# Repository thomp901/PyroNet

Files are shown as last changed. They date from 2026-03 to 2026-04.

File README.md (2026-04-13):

# PyroNet
Early Fire Detection: Purdue Senior Design Project

Team Members:
Sebastian Carrizosa
Kameron Jackson
Diego Ramirez
Garrison Thompson

## Download Specific Folders

To download **only** the a specific folder (e.g. hardware/, csp/) that contains the relevant files, run the following commands:

```bash
git clone --filter=blob:none --no-checkout https://github.com/thomp901/PyroNet.git
cd PyroNet
git sparse-checkout init --cone
git sparse-checkout set FOLDER/
git checkout main
```

Replace `FOLDER` with the specfic folder.

Then, you can `pull`, `add`, `commit`, and `push` like normal.

## Pushing

To push, go to the project directory in your terminal and enter the following commands:

```bash
git add .
git commit -m 'YOUR MESSAGE'
git push
```

Replace `YOUR MESSAGE` with a brief description of your changes.

## Discarding your changes

To **discard your changes** and pull the latest version, enter: 

```bash
git fetch --all
git reset --hard origin/main
```

> [!WARNING]
> Warning: This will permanently delete any local work.

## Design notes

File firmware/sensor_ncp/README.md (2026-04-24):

## sensor_ncp

This project builds the `sensor_ncp` firmware for the custom `BDE-MB1352P71` carrier-board target in this repository. It is not a LaunchPad project, even though SysConfig still uses `LP_CC1352P7_1` as the generic device context.

The current host boundary is a phase-1 binary UART protocol on `UART0`:

- UART pins: TX=`DIO_28`, RX=`DIO_27`
- UART settings: `115200 8N1`, no flow control
- Framing: `0xA5 0x5A`, version `0x01`, CRC-16/CCITT-FALSE
- Implemented message types: `HELLO`, `HELLO_ACK`, `PING`, `PONG`, `GET_STATUS`, `STATUS`, `ERROR`

The NCP owns only the link skeleton in this phase:

- waits for `HELLO`
- replies with `HELLO_ACK`
- enters `LINK_READY`
- responds to `PING` with `PONG`
- responds to `GET_STATUS` with placeholder `STATUS`

The production UART boundary is binary only. The earlier ASCII command bootstrap path is no longer the active transport.

## Hardware Notes

- Target module: `BDE-MB1352P71`
- Verified SWO / ITM trace pin: `DIO_16`
- Reserved BDE module pins must remain untouched:
  - `DIO_8`, `DIO_9`, `DIO_10`, `DIO_20` are used by on-module SPI flash
  - `DIO_29`, `DIO_30` are used by the RF switch
- XOSC cap settings for this module must remain:
  - `CCFG.xoscCapArray = true`
  - `CCFG.xoscCapArrayDelta = 0x00`

## Verified Build

```sh
cd /Users/diegosmacbook/Documents/PyroNet/firmware/sensor_ncp
make -C freertos/ticlang \
  SIMPLELINK_CC13XX_CC26XX_SDK_INSTALL_DIR=/Users/diegosmacbook/ti/simplelink_cc13xx_cc26xx_sdk_8_32_00_07 \
  SYSCONFIG_TOOL=/Applications/ti/ccs2050/ccs/utils/sysconfig_1.27.0/sysconfig_cli.sh \
  TICLANG_ARMCOMPILER=/Applications/ti/ti-cgt-armllvm_5.1.0.LTS \
  clean all
```

Build output:

- `freertos/ticlang/sensor_ncp.out`

## Verified Flash

```sh
cd /Users/diegosmacbook/Documents/PyroNet/firmware/sensor_ncp
/Applications/ti/uniflash_9.5.0/dslite.sh \
  --config=tools/cc1352p7_2pin_cJTAG_XDS110.ccxml \
  -e \
  freertos/ticlang/sensor_ncp.out
```

## Wi-SUN Profile

The current image is configured for the running PyroNet border router:

- FAN: `1.1`
- Device role: `FFN`
- Network name: `PyroNet`
- Regulatory domain: `NA`
- Channel plan ID: `1`
- PHY mode ID: `0x02`
- Security: certificate-based

Repo-local credentials are expected at:

- `certs/ca_cert.pem`
- `certs/node_cert.pem`
- `certs/node_key.pem`

These are compiled through `application/wisun_certificates.h`.

## Verified Runtime Status

The current image has been verified to:

- boot on the custom board
- emit SWO / ITM trace on `DIO_16`
- start the TI Wi-SUN stack
- reach `CON_STATUS_CONNECTING` in local trace output
- join the running `PyroNet` border router

Join success was confirmed from the border-router side by observing:

- advertisement and configuration exchange
- DHCPv6 reply
- ARO registration for `fd12:3456::212:4b00:28ed:d802`
- RPL DAO and DAO-ACK

## SWO / ITM Capture

Verified helper:

```sh
cd /Users/diegosmacbook/Documents/PyroNet/firmware/sensor_ncp
python3 tools/capture_itm_text.py /dev/cu.usbmodemLS41069U4 3000000 --seconds 15
```

Repo-root shortcuts:

```sh
make build
make flash
make run
make watch
make bootlog
```

Persistent logging:

```sh
cd /Users/diegosmacbook/Documents/PyroNet/firmware/sensor_ncp
python3 tools/swo_log_daemon.py
```

This writes timestamped daily files under `logs/swo/` and will reconnect if the XDS110 aux port disappears and reappears.

Persistent terminal trace:

```sh
cd /Users/diegosmacbook/Documents/PyroNet/firmware/sensor_ncp
make watch
```

This starts the TI DSS probe hold-open session and streams decoded SWO text directly in the terminal while also writing `logs/swo/swo_YYYY-MM-DD.log`. On Apple Silicon, the wrapper will automatically use TI's bundled x86_64 Java runtime when available.

To install it as a macOS user `launchd` agent:

```sh
cd /Users/diegosmacbook/Documents/PyroNet/firmware/sensor_ncp
python3 tools/install_swo_logger_launchd.py install
```

Notes:

- the exact `/dev/cu.usbmodem...` node may vary
- `make watch` auto-detects the XDS110 aux port by default; set `SWO_PORT=/dev/cu.usbmodem...` to pin it
- this hardware uses the XDS110 aux COM path mapped to target `TDO` on `DIO_16`
- `tools/capture_itm_text.py` includes a fallback decoder for this image's raw SWO byte pattern
- the simplest reliable one-shot capture is `make bootlog`, which starts capture first and then reflashes to force a fresh boot

## Reference Trees

These are reference-only and must not be edited in place:

- `../wisun_soc_cli`
- `../wisun_rcp`
- TI SDK example content under `/Users/diegosmacbook/ti/simplelink_cc13xx_cc26xx_sdk_8_32_00_07`

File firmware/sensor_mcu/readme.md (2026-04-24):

# sensor_mcu

This firmware exposes a dedicated SWO debug path through [debug_console.c](./debug_console.c)
and [debug_console.h](./debug_console.h). The implementation uses:

- ITM stimulus port `0` for application log output
- PA03 as the SWO pin
- NRZ SWO at a target bitrate of `875000`
- a stable boot-ready marker of `SWO_BOOT_READY`

The firmware emits two boot lines during `app_init()`:

- `SWO_BOOT backend=SWO port=0 speed=<actual>`
- `SWO_BOOT_READY`

The current sensor bring-up path also probes and initializes the shared I2C bus
during `app_init()`:

- SPS30 at address `0x69`
- BME68x at address `0x76`

Probe output is emitted over the same log path from [sensor_bus.c](./sensor_bus.c):

- `SENSOR_FOUND name=SPS30 addr=0x69` when the SPS30 ACKs
- `SENSOR_PROBE name=SPS30 addr=0x69 status=<status>` when the SPS30 does not ACK cleanly
- `BSEC_READY addr=0x76` when the BME688/BSEC stack is initialized
- `SPS30_READY addr=0x69 fw=<major>.<minor>` when the SPS30 stack is initialized
- `SENSORS_READY bme68x=<0|1> sps30=<0|1>` after bring-up completes, reflecting
  initialized sensor services rather than probe-only presence

Once boot is complete, the firmware runs the non-stretch sensing path:

- BME688/BSEC air-quality acquisition with one immediate bootstrap reading on
  the first successful BME688 measurement, then a fixed 10-second app cadence
- PM2.5 acquisition through the SPS30 on the same fixed 10-second app cadence
- `SENSOR_READING ...`, `GAS_DIAGNOSTIC ...`, and `RISK_LEVEL ...` SWO lines
  when live sensor readings are forwarded into the risk service

Use the repo `Makefile` for the normal host workflow:

```sh
make verify-swo
```

That will build, flash, and read SWO until `SWO_BOOT_READY` is observed.

To read SWO directly through the SI-DBG1015A in SWD mode, run:

```sh
"$HOME/.silabs/slt/installs/archive/Commander.app/Contents/MacOS/commander" \
  swo read \
  --device EFR32FG28A122F1024GM48 \
  --serialno 440365444 \
  --tif SWD \
  --swospeed 875000 \
  --timeout 5 \
  --endmarker "SWO_BOOT_READY"
```

Use `--noreset` if the target is already running and you only want to attach to
an existing session, or run:

```sh
make swo-attach TIMEOUT=5
```

If you add temporary SWO diagnostics while debugging, keep them short and
remove or reduce them once verification is complete.

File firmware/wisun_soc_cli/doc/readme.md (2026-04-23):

# Wi-SUN - SoC CLI

The Wi-SUN CLI (Command-Line Interface) sample application allows developers to easily evaluate the Wi-SUN stack APIs. The Wi-SUN command-line interface provides a serial interface to a number of the Wi-SUN stack functions. For example, it can be used to connect the Wi-SUN device to a Wi-SUN border router and exchange IP packets or perform RF tests.

## Getting Started

To get started with Wi-SUN and Simplicity Studio, see [QSG181: Wi-SUN SDK Quick Start Guide](https://www.silabs.com/documents/public/quick-start-guides/qsg181-wi-sun-sdk-quick-start-guide.pdf).

> NB: The Wi-SUN CLI application, as opposed to most other Wi-SUN sample applications, is not in 'auto-connect' mode by default. This means that the user has to set the network parameters and trigger the connection manually following a reset. This is visible when calling `wisun get wisun.join_state` in the console (the result will be `wisun.join_state = Disconnected (0)`). To change this behavior, use `wisun set app.autoconnect 1` followed by `wisun save` (when 'auto-connect' is active, a `Connecting...` message will be visible following a reset, with `Join_state: Select PAN...`).

This example exposes a command-line interface to interact with the Wi-SUN stack. To get started with the example, follow the steps below:

* Flash the "Wi-SUN Border Router" demonstration to a device and start the Border Router.
* Create and build the Wi-SUN CLI project.
* Flash the Wi-SUN CLI project to a second device.
* Using Simplicity Studio, open a console on the device running the Wi-SUN CLI project.

See the associated sections in [QSG181: Wi-SUN SDK Quick Start Guide](https://www.silabs.com/documents/public/quick-start-guides/qsg181-wi-sun-sdk-quick-start-guide.pdf) for step-by-step guidelines for each operation. To fully evaluate the Wi-SUN CLI features, another device running the Wi-SUN CLI application might be required. The Wi-SUN CLI application can also interact with the other Wi-SUN examples (Wi-SUN Ping, Wi-SUN TCP/UDP Server/Client...).

> The Wi-SUN CLI example can be used to evaluate and test the Wi-SUN stack but should not be used to create production applications (due to its large footprint related to all PHYs being allowed). Developers should implement their own C application running in the EFR32 and using the Wi-SUN stack API, starting from simpler example applications.

## Wi-SUN CLI Commands

To see the available commands, enter the following command in the console.

    wisun help

The list of available commands is output on the console with the associated help. Following is an extended description and examples of how to use each command.

| Command | Description | Example |
|---|---|---|
| wisun get \<section>.[setting] | Get a setting variable. Specifying only the section retrieves all settings of the section. | > wisun get wisun.ip_addresses<br>> wisun get wisun <br>>  wisun get wisun.join_state <br>> wisun get statistics <br>> wisun get app |
| wisun set \<section>.[setting] \<value> | Set a setting variable | > wisun set wisun.network_size test |
| wisun join_fan10 | Connect to the selected Wi-SUN FAN1.0 network | > wisun join_fan10 |
| wisun join_fan11 | Connect to the selected Wi-SUN FAN1.1 network | > wisun join_fan11 |
| wisun join_explicit | Connect to a Wi-SUN (FSK only) network using explicit channel settings| > wisun join_explicit |
| wisun join_ids | Connect to a Wi-SUN network using radio conf ids| > wisun join_ids |
| wisun join_custom_fsk | Connect to a Wi-SUN network using custom FSK PHY settings | > wisun join_custom_fsk |
| wisun join_custom_ofdm | Connect to a Wi-SUN network using custom OFDM PHY settings | > wisun join_custom_ofdm |
| wisun join_custom_oqpsk | Connect to a Wi-SUN network using custom OQPSK PHY settings | > wisun join_custom_oqpsk |
| wisun disconnect | Disconnect from the Wi-SUN network | > wisun disconnect |
| wisun mac_allow \<mac address> | Add an allowed MAC address to the access list<br>broadcast address: allow all MAC addresses<br>unique address: allow the given MAC address | > wisun mac_allow ff:ff:ff:ff:ff:ff:ff:ff<br>> wisun mac_allow ffffffffffffffff |
| wisun mac_deny \<mac address>  | Add a denied MAC address to the access list<br>broadcast address: deny all MAC addresses<br>unique address: deny the given MAC address | > wisun mac_deny 00:01:02:03:04:05:06:07<br>> wisun mac_deny 0001020304050607 |
| wisun ping \<remote address> | Ping a remote host | > wisun ping fd00:7283:7e00:0:fd6f:d00:a8c0:20fe |
| wisun reset | Reset variables to default values | > wisun reset |
| wisun save | Save variables to NVM | > wisun save |
| wisun socket_close \<socket> | Close an open socket | > wisun socket_close 3 |
| wisun socket_list | List open sockets | > wisun socket_list |
| wisun socket_read \<socket> \<amount of bytes> | Read buffered data from a socket | > wisun socket_read 3 14 |
| wisun socket_set_option \<socket> \<option> \<option data> | Configure a socket | > wisun socket_set_option 3 event_mode indication |
| wisun socket_write \<socket> \<string> | Write a string to a socket | > wisun socket_write 3 "hello world" |
| wisun socket_writeto \<socket> \<remote address> \<remote port> \<string\> | Write a string to an unconnected socket, i.e. UDP server socket | > wisun socket_writeto 3 fc00::1 5001 "hello world" |
| wisun tcp_client \<remote address> \<remote port> | Open a TCP connection to a remote host | > wisun tcp_client fd24:120b:802c:0001:705d:9179:8607:fd21 5001 |
| wisun tcp_server \<local port> | Open a TCP server port | > wisun tcp_server 5001 |
| wisun udp_client \<remote address> \<remote port> | Open a UDP connection to a remote host | > wisun udp_client fd00:6172:6d00:0:3038:5115:26:27 7 |
| wisun udp_server \<local port> | Open a UDP server port | > wisun udp_server 5001 |
| wisun socket_get_option \<socket> \<option> | Get a socket option | > wisun socket_get_option |
| wisun clear_credential_cache | Clear the wisun credential cache | > wisun clear_credential_cache |
| wisun reset_statistics | Reset the statistics | > wisun reset_statistics |
| wisun set_trace_level \<string> | Set [trace level](https://docs.silabs.com/wisun/latest/wisun-stack-api/sl-wisun-types#sl-wisun-trace-level-t) for a [trace group](https://docs.silabs.com/wisun/latest/wisun-stack-api/sl-wisun-types#sl-wisun-trace-group-t) | > wisun set_trace_level all,debug<br>[Set 64 trace groups]<br>> wisun set_trace_level 1,none;4,info<br>[Set 2 trace groups]|
| wisun set_lfn_support \<lfn_limit> | configure LFN support: <br> - [uint8] lfn_limit: Number of LFN children | > wisun set_lfn_support 3 |
| wisun mode_switch \<mode> \<phy_mode_id> \<neighbor_mac_address> |  configure mode switch: <br> - [uint8] mode: 0=disabled, 1=enabled, 2=default <br> - [uint8] PhyModeID <br> - [string] neighbor MAC address (optional) | > wisun mode_switch 1 84 <br> > wisun mode_switch 1 84 01:02:03:04:05:06:07:08 |
| wisun trigger \<frame type> | Trigger a transmission of a periodic frame <br> - [string] pas: PAN Advertisement Solicit, pa: PAN Advertisement, pcs: PAN Configuration Solicit, pc: PAN Configuration, dis: DODAG Information Solicitation, dio: DODAG Information Object | > wisun trigger pas |
| wisun getsockname \<socket> | Get local IP address of the socket | > wisun getsockname 3 |
| wisun getpeername \<socket> | Get peer IP address of the socket | > wisun getpeername 3 |
| wisun set_leaf \<is_leaf> | Set Leaf behavior <br> - [uint8] state: 0=disabled, 1=enabled <br> | > wisun set_leaf 1 |
| wisun set_phy_sens \<phy_mode_id> \<sensitivy> | Set the sensitivity for the given PhyModeID <br> - [uint8] PhyModeID <br> - [int16] sensitivy in dBm | > wisun set_phy_sens 1 -70 |
| wisun set_direct_connect_state \<state> | Set Direct Connect state <br> - [uint8] state: 0=disabled, 1=enabled <br> | wisun set_direct_connect_state 1 |
| wisun accept_direct_connect_link \<remote address> | Accept a Direct Connect link request | wisun accept_direct_connect_link fe80::b6e3:f9ff:fec5:83df |
| wisun concurrent_detection \<state> | Configure concurrent detection <br> - [uint8] state: 0=disabled, 1=enabled <br> | > wisun concurrent_detection 1 |
| wisun reset_duty_cycle | Reset the duty cycle counters | > wisun reset_duty_cycle |

## Wi-SUN Settings

The command-line interface maintains a number of settings. The Wi-SUN settings are distributed in three sections: *wisun*, *statistics*, and *app*. They can be listed by entering:

    wisun get <section name>

The Wi-SUN stack settings are listed with their current state/value. Some of them can be modified by using the following command prototype:

    wisun set <section name>.<settings name> <value>

To modify the network name the Wi-SUN device should connect to, enter:

    wisun set wisun.network_name "My Network"

Next time you issue the `wisun join_xxxxx` command, the device starts a connection process with the Wi-SUN network named "My Network".

### Matching a `wsbrd` Border Router

For a border router configured with:

    network_name = Wi-SUN\x20Network
    domain = NA
    chan_plan_id = 1
    phy_mode_id = 0x02

the default client settings in this project already match those values through `config/wisun/wisun_settings.wisunconf`.

The equivalent runtime CLI commands are:

    wisun set wisun.network_name "Wi-SUN Network"
    wisun set wisun.regulatory_domain NA
    wisun set wisun.chan_plan_id 1
    wisun set wisun.phy_mode_id 2
    wisun save

This project also stores the client credential material in `config/wisun/wisun_settings.wisunconf`:

- `devicePrivateKey`: node private key
- `deviceCertificate`: node certificate
- `caCertificate`: trusted CA certificate

These must match the border router CA, while the node certificate and key must remain distinct from the border router certificate and key.

### *wisun* Section Settings

- The settings in the *wisun* section are directly related to the Wi-SUN stack behavior. A detailed settings list can be found below.
- Writable settings are valid for all PHYs unless it is specified otherwise in the last column .

| Variable | R/W | Type | Values | Description | Applies to |
|---|-----|---|---|---|---|
| wisun.network_name | R/W | string | up to 31 ASCII characters. Use double quotes (") to include spaces | Name of the Wi-SUN network |  |
| wisun.phy_config_type | R | string | - FAN1.0 (0) <br> - FAN1.1 (1) <br> - explicit (2) <br> - IDs (3) | Wi-SUN PHY configuration type (depends on the `wisun join_xxxx` used) |  |
| wisun.regulatory_domain | R/W | integer | - WW (0): Worldwide<br> - NA (1): North America<br> - JP (2): Japan<br> - EU (3): Europe<br> - CN (4): China<br> - IN (5): India<br> - MX (6): Mexico<br> - BZ (7): Brazil<br> - AZ (8): Australia/New Zealand<br> - KR (9): South Korea<br> - PH (10): Philippines<br> - MY (11): Malaysia<br> - HK (12): Hong Kong<br> - SG (13): Singapore<br> - TH (14): Thailand<br> - VN (15): Vietnam | Regulatory domain of the Wi-SUN network | - FAN1.0 <br> - FAN1.1 |
| wisun.operating_class | R/W | integer | 1 to 4 | Wi-SUN FAN1.0 operating class | FAN1.0 |
| wisun.operating_mode | R/W | integer | - 0x1a (1a) <br> - 0x1b (1b) <br> - 0x2a (2a) <br> - 0x2b (2b) <br> - 0x3 (3) <br> - 0x4a (4a) <br> - 0x4b (4b) <br> - 0x5 (5) | Wi-SUN FAN1.0 operating mode | FAN1.0 |
| wisun.network_size | R/W | integer | - automatic (0) <br> - small (default): less than 100 nodes (1) <br> - medium: 100 to 1000 nodes (2) <br> - large: more than 1000 nodes (3) <br> - test (4) <br> - certification (6) |  Used to optimize network timings considering the number of expected nodes on the network. |  |
| wisun.tx_power | R/W | integer | -45 to 20 | Maximum TX power in dBm |  |
| wisun.tx_power_ddbm | R/W | integer | -450 to 200 | Maximum TX power in deci-dBm |  |
| wisun.unicast_dwell_interval | R/W | integer | 10 to 255 | Unicast dwell interval in milliseconds |  |
| wisun.chan_plan_id | R/W | integer | - Europe: 32-37 <br> - North America: 1-5 <br> - Brazil: 1-5 <br> - Japan: 21-24 | Wi-SUN channel plan ID [uint8] | FAN1.1 |
| wisun.phy_mode_id | R/W | integer | - Europe: <br> FSK without FEC: 1/3/5 <br> FSK FEC: 17/19/21 <br> OFDM: 84-86 <br> - North America: <br> FSK without FEC: 2/3/5/6/8 <br> FSK FEC: 18/19/21/22/24 <br> OFDM: 34-38 / 51-54 / 68-70 / 84-86 <br> - Brazil: <br> FSK without FEC: 2/3/5/6/8 <br> FSK FEC: 18/19/21/22/24 <OFDM> 34-38 / 51-54 / 68-70 / 84-86 <BR> - Japan: <br> FSK without FEC: 2/4/5/7/8 <br> FSK FEC: 18/20/21/23/24 <br> OFDM: 51-54 / 68-70 / 84-86 | Wi-SUN FAN1.1 PHY mode ID | - FAN1.1 <br> - explicit <br> - join by IDs |
| wisun.ch0_frequency | R/W | integer |  | Explicit channel plan: Central frequency of the first channel in kHz | explicit |
| wisun.channel_spacing | R/W | integer | - 100 kHz (0) <br> - 200 kHz (1) <br> - 400 kHz (2) <br> - 600 kHz (3) <br> - 250 KHz (4) <br> - 800kHz (5) <br> - 1200KHz (6) | Explicit channel plan: Channel spacing | explicit |
| wisun.number_of_channels | R/W | integer |  | Explicit channel plan: Number of channels | explicit |
| wisun.protocol_id | R/W | integer |  | Radioconf protocol ID [uint16] | join by IDs |
| wisun.channel_id | R/W | integer |  | Radioconf channel ID [uint16] | join by IDs |
| wisun.ip_addresses | R | list of IPv6 addresses |  | List of all IP addresses assigned to the device |  |
| wisun.border_router | R | list of IPv6 addresses |  | List of known IPv6 addresses of the border router | |
| wisun.parents | R | list of IPv6 addresses |  | List of known IPv6 addresses of the parents |  |
| wisun.neighbors | R | list of IPv6 addresses |  | List of known IPv6 addresses of the RPL neighbors  |  |
| wisun.join_state | R | integer | - Idle (0) <br> - Select PAN (1) <br> - Authenticate (2) <br> - Acquire PAN Config (3) <br> - Configure Routing (4) <br> - Operational (5) | Current join state in the connection process |  |
| wisun.mac_address | R/W | MAC address |  | MAC address to use |  |
| wisun.allowed_channels | R/W | string |  | Allowed channel ranges (e.g. 0-54,57-60,64,67-68) |  |
| wisun.fec | R/W | bool | - disable FEC (0) <br> - enable FEC (1) | Use FEC flag | FAN1.0 |
| wisun.regulation | R/W | string | - None (0) <br> - ARIB (1) | Regional regulation |  |
| wisun.regulation_warning_threshold | R/W | integer | - threshold value (0-100) <br> - disable (-1) | Transmission power warning threshold in percent (-1 to disable)|  |
| wisun.regulation_alert_threshold | R/W | integer | - threshold value (0-100) <br> - disable (-1) | Transmission power alert threshold in percent (-1 to disable) |  |
| wisun.device_type | R/W | string | - FFN: Full Function Node (0) <br> - LFN: Limited Function Node (1) | Device type |  |
| wisun.trace_filter.000-031 | R/W | hexadecimal | (Refer to sl_wisun_types.h / `sl_wisun_trace_group_t` for a list of all 37 trace groups)| RTT Trace filter enable bitfield for first 32 groups |  |
| wisun.trace_filter.032-063 | R/W | hexadecimal | (Refer to sl_wisun_types.h / `sl_wisun_trace_group_t` for a list of all 37 trace groups)| RTT Trace filter enable bitfield for last  32 groups |  |
| wisun.lfn_profile | R/W | integer | - Test (0) <br> - Balanced (1) <br> - Eco (2) | Wi-SUN LFN profile | FAN1.1 |
| wisun.rx_phy_mode_ids | R/W | integer | list of phy_mode_ids | List of PhyModeId to advertise in POM-IE | FAN1.1 |
| wisun.crc_type | R/W | integer | - no CRC (0) <br> - 2-byte CRC (1) <br> - 4-byte CRC (2) | CRC for custom FSK/OFDM/OQPSK PHY | |
| wisun.preamble_length | R/W | integer | | Preamble length in bits for custom FSK/OQPSK PHY | |
| wisun.stf_length | R/W | integer | | Short Training Field length in symbols for custom OFDM PHY | |
| wisun.async_channel_mask | R | xx:...:xx | - Not masked (0) <br> - Masked (1) | Excluded channel mask applied to async frames | |
| wisun.unicast_channel_mask | R | xx:...:xx | - Not masked (0) <br> - Masked (1) | Excluded channel mask applied to unicast frequency hopping | |
| wisun.broadcast_channel_mask | R | xx:...:xx | - Not masked (0) <br> - Masked (1) | Excluded channel mask applied to broadcast frequency hopping | |
| wisun.max_child_count | R/W | integer | 1 to 254 | Maximum number of RPL children | |
| wisun.max_neighbor_count | R/W | integer | 1 to 254 | Size of the neighbor table, including temporary entries and RPL parents | |
| wisun.max_security_neighbor_count | R/W | integer | 1 to 254 | Size of the security neighbor table | |
| wisun.preferred_pan_id | R/W | integer | 0 to 65535 | Preferred PAN ID (0xFFFF to disable) | |
| wisun.keychain | R/W | integer | - automatic (0) <br> - built-in (1) <br> - NVM (2) | Keychain to use for device credentials | |
| wisun.keychain_index | R/W | integer | 0 to 255 | Device credential index to use for built-in keychain | |
| wisun.direct_connect_pmk \<pmk> | R/W | string | 64 hex characters | Preshared Master Key for Direct Connect |
| wisun.max_hop_count | R/W | integer | 1 to 24 | Hop count after which the node automatically enables the RPL leaf mode |
| wisun.lowpan_mtu | R/W | integer |  | Maximum size of 6LoWPAN packets after which packets are fragmented |
| wisun.ipv6_mru | R/W | integer |  | Maximum size of a fragmented IPv6 packet the node is willing to accept after reassembly |
| wisun.max_edfe_fragment_count | R/W | integer | 0 - 10 | Maximum amount of 6LoWPAN/IPv6 fragments to send in a single EDFE exchange |
| wisun.socket_rx_buffer_size | R/W | integer |  | Socket receiver buffer size for ICMP echo requests |

#### Non-Standard ('explicit') Channel Plan

Customers willing to experiment with non-standard frequency plans need to set:

* `wisun.regulatory_domain 255`
* `wisun.operating_class 255`
* `wisun.ch0_frequency`
* `wisun.channel_spacing`
* `wisun.number_of_channels`
* `wisun.channel_mask`

and join the network using `wisun join_explicit`

### *statistics* Section Settings

The settings part of the *statistics* section are counters maintained by the Wi-SUN stack. A detailed setting list is available below.

| Variable | Read/Write | Description |
|---|---|---|
| statistics.phy | R | PHY statistics |
| statistics.mac | R | MAC statistics |
| statistics.fhss | R | Frequency hopping statistics |
| statistics.wisun | R | Wi-SUN layer statistics |
| statistics.network | R | 6LoWPAN/IP stack statistics |
| statistics.regulation | R | Regional regulation statistics and errors |
| statistics.heap | R | Memory consumption statistics |

### *info* Section Settings

The settings part of the *info* section contain information about the connected Wi-SUN network. A detailed setting list is available below.

| Variable | Read/Write | Description |
|---|---|---|
| info.network | R | Wi-SUN network information |
| info.rpl | R | RPL information |

### *app* Section Settings

The settings in the *app* section relate to the application options. A detailed setting list is available below.

| Variable | R/W | Type | Values | Description |
|---|---|---|---|---|
| app.printable_data_length | R/W | integer | 0: received socket data is not printed<br>1 - 64: amount of characters per line | If enabled, received socket data is printed |
| app.printable_data_as_hex | R/W | integer | 0: print received socket data as ASCII<br>1: print received socket data as hex | Output type for received socket data |
| app.autoconnect | R/W | bool | 0: disable autoconnect<br>1: enable autoconnect | Enable or disable autoconnect [bool] |
| app.pti_state | R/W | bool | 0: disable PTI <br>1: enable PTI | Disable or enable PTI |

## *ping* Section Settings

The settings in the *ping* section relate to the ping command. A detailed setting list is available below.

| Variable | R/W | Type | Values | Description |
|---|---|---|---|---|
| ping.identifier | R/W | integer | 0 - 65535 | Identifier to aid in matching ICMPv6 Echo Requests and Replies |
| ping.sequence_number | R/W | integer | 0 - 65535 | Sequence number to aid in matching ICMPv6 Echo Requests and Replies |
| ping.packet_length | R/W | integer | 8 - 2048  | Length of ICMPv6 Echo Request packet in bytes, including the header |
| ping.pattern | R/W | string | | Repeating pattern used to fill ICMPv6 Echo Request payload |

## RF test Commands

To see the available commands, enter the following command in the console.

    rftest help

The list of available commands is output on the console with the associated help. The following is an extended description and examples of how to use each command.

| Command | Description | Example |
|---|---|---|
| rftest start_stream \<channel ID> | Start an RF test stream on a specific channel | > rftest start_stream 5<br>RF Test stream started 21 |
| rftest stop_stream | Stop the RF test | > rftest stop_stream<br>RF Test stream stopped 2 |
| rftest start_tone \<channel ID>| Start an RF test tone on a specific channel | > rftest start_tone 5<br>RF Test tone started 21|
| rftest stop_tone | Stop RF test tone | > rftest stop_tone<br>RF Test tone stopped 2|
| rftest set_tx_power \<value> | Set Tx power for the RF test in dBm |> rftest set_tx_power 17<br>RF Test tx Power set to  17|

## RTT traces

To control RTT traces, set the trace level using `wisun set_trace_level [group_id],[trace level];`

All RTT trace groups and trace levels are listed in `sl_wisun_types.h/sl_wisun_trace_group_t`

    typedef enum {
    SL_WISUN_TRACE_GROUP_MAC     = 0,     /// Mac
    SL_WISUN_TRACE_GROUP_NW      = 1,     /// Network
    SL_WISUN_TRACE_GROUP_LLC     = 2,     /// LLC
    SL_WISUN_TRACE_GROUP_6LO     = 3,     /// 6lowpan
    SL_WISUN_TRACE_GROUP_IPV6    = 4,     /// IPV6
    . . .
    Sl_WISUN_TRACE_GROUP_WSIE    = 35,    /// Wi-SUN IE
    SL_WISUN_TRACE_GROUP_CONFIG  = 36,    /// Configuration
    // 36 to 63 reserved for future used
    SL_WISUN_TRACE_GROUP_INT     = 63,    /// Internal usage
    SL_WISUN_TRACE_GROUP_COUNT   = 64     /// Max number of trace group in this enum
    } sl_wisun_trace_group_t;
    . . .
    typedef enum {
    /// No trace
    SL_WISUN_TRACE_LEVEL_NONE  = 0,
    /// Error only
    SL_WISUN_TRACE_LEVEL_ERROR = 1,
    /// Warning + error
    SL_WISUN_TRACE_LEVEL_WARN  = 2,
    /// Info + warning + error
    SL_WISUN_TRACE_LEVEL_INFO  = 3,
    /// Debug + info + warning + error
    SL_WISUN_TRACE_LEVEL_DEBUG = 4,
    } sl_wisun_trace_level_t;

Example: to set 'Network' to 'Debug' and 'IPV6' to 'Warning', use:

`wisun set_trace_level 1,0;4,4;` or `wisun set_trace_level 1,none;4,debug;`

## Troubleshooting

Before programming the radio board mounted on the WSTK, ensure the power supply switch is in the AEM position (right side), as shown.

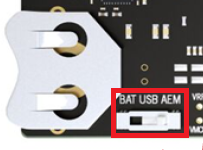
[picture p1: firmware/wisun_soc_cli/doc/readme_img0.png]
Radio Board Power Supply Switch


## Resources

* [Wi-SUN Stack API documentation](https://docs.silabs.com/wisun/latest)
* [AN1330: Wi-SUN Mesh Network Performance](https://www.silabs.com/documents/public/application-notes/an1330-wi-sun-network-performance.pdf)
* [AN1332: Wi-SUN Network Setup and Configuration](https://www.silabs.com/documents/public/application-notes/an1332-wi-sun-network-configuration.pdf)
* [AN1364: Wi-SUN Network Performance Measurement Application](https://www.silabs.com/documents/public/application-notes/an1364-wi-sun-network-performance-measurement-app.pdf)
* [QSG181: Wi-SUN Quick-Start Guide](https://www.silabs.com/documents/public/quick-start-guides/qsg181-wi-sun-sdk-quick-start-guide.pdf)
* [UG495: Wi-SUN Developer's Guide](https://www.silabs.com/documents/public/user-guides/ug495-wi-sun-developers-guide.pdf)

## Report Bugs & Get Support

You are always encouraged and welcome to ask any questions or report any issues you found to us via [Silicon Labs Community](https://community.silabs.com/s/topic/0TO1M000000qHc6WAE/wisun).

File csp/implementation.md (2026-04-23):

# Persistence Implementation

This document tracks the phased implementation of gateway-to-CSP persistence for binary backhaul ingest. Update it as development progresses so scope, status, and sequencing stay aligned with the codebase.

## Boundary

- This workstream is limited to CSP-side persistence and ingest handling.
- It does not implement gateway firmware, durable outbox behavior at the gateway, CoAP termination, Wi-SUN border-router logic, or mesh delivery/retry behavior.
- Gateway-observed fields such as source IPv6 are persisted as reported metadata for CSP use; they do not make the CSP authoritative for border-router state.

## Status Legend

- `not_started`: phase has not begun
- `in_progress`: active development
- `blocked`: waiting on a decision or prerequisite
- `done`: implemented and verified at the intended scope

## Current Focus

- Workstream: durable persistence for gateway registration and node uplink ingest
- Primary files expected to change first: [server/index.ts](/home/diego/PyroNet/csp/server/index.ts), [src/api/types.ts](/home/diego/PyroNet/csp/src/api/types.ts)
- Current active phase: Phase 8 when resumed

## Update Rules

- Update phase status when development starts or completes.
- Add concrete file references under each phase as implementation lands.
- Record blocked decisions in the open questions section instead of letting them stay implicit.
- Keep this document focused on persistence and ingest; UI follow-on work can be linked here but should not dominate the plan.

## Open Questions

- `bvoc_ppm` wire encoding is still unspecified for both telemetry and config payloads.
- Permanent reject criteria for `0x83.status = 0x01` need to be defined precisely.
- Historical storage requirements for parent updates (`0x08`) need to be confirmed.
- Gateway registration deduplication behavior should be specified explicitly.
- The `0x82` uplink envelope size text says `36 + N`, but the packed struct fields sum to `34 + N`; codec work currently follows the struct field sizes.
- The current relational telemetry column is still named `voc_iaq`; Phase 5 projection currently maps `bvoc_ppm` raw values there as an interim fit pending a schema rename or clearer unit decision.

## Current Behavior Notes

- CSP ingest now accepts private IPv6 ULA addresses such as Tailscale `fd...` ranges for observed node and parent addresses.
- CSP still rejects invalid IPv6 categories for these fields, including unspecified, loopback, multicast, and link-local addresses.
- CSP now uses stable permanent-reject codes for parse-stage and validation-stage terminal failures.
- Projection-stage semantic failures are retryable and currently surface as server errors rather than terminal `0x83` rejects.

## Phases

### Phase 0 - Contract Freeze

- Status: `not_started`
- Goal: lock the persistence-facing protocol assumptions before schema or handler work begins
- Scope:
- finalize backhaul `version` policy
- define terminal reject reasons for malformed, unsupported, and semantically invalid envelopes
- define idempotency contract for `(gateway_id, uplink_id)`
- define which fields are persisted raw vs projected into application tables
- Exit criteria:
- binary ingest contract is stable enough to encode in SQL constraints and handler validation
- unresolved wire-format questions are listed explicitly in this file
- Planned artifacts:
- protocol notes in this document
- validation rules implemented in server code later

### Phase 1 - Persistence Foundation

- Status: `in_progress`
- Goal: create durable storage for backhaul envelopes and receipts
- Scope:
- add gateway identity tables
- add gateway registration history
- add durable uplink inbox or raw envelope table
- add terminal receipt tracking and optional dead-letter storage
- enforce uniqueness on `(gateway_id, uplink_id)`
- preserve raw payload bytes and observed metadata for replay/audit
- Exit criteria:
- schema can durably store every inbound `0x81` and `0x82`
- duplicate uplinks can be detected without reprocessing side effects
- Implemented so far:
- added schema support for `gateways` and `gateway_registrations`
- added durable `gateway_uplinks` storage keyed by `(gateway_id, uplink_id)`
- added terminal receipt and dead-letter tables for replay-safe auditability
- Planned files:
- [schema.sql](/home/diego/PyroNet/csp/schema.sql)

### Phase 2 - Binary Codec Layer

- Status: `done`
- Goal: parse and validate binary backhaul messages independently from HTTP routing
- Scope:
- decode `0x81` gateway registration
- decode `0x82` uplink envelope
- emit `0x83` terminal receipt
- decode inner node payloads `0x01`, `0x02`, `0x03`, `0x08`
- validate payload sizes, supported versions, and field bounds
- Exit criteria:
- handler code can depend on typed parse results instead of raw buffers
- malformed payloads can be rejected deterministically
- Implemented so far:
- added [server/backhaulCodec.ts](/home/diego/PyroNet/csp/server/backhaulCodec.ts) with binary parsing for `0x81`, `0x82`, `0x83`
- added inner payload decoding for `0x01`, `0x02`, `0x03`, and `0x08`
- added strict length, version, coordinate, battery, risk-level, and IPv6 validation
- Planned files:
- [server/index.ts](/home/diego/PyroNet/csp/server/index.ts) or a new server-side codec module

### Phase 3 - Gateway Registration Persistence

- Status: `done`
- Goal: persist `POST /api/v1/gateways/register` requests as binary registrations
- Scope:
- add octet-stream request handling
- parse and validate `0x81`
- upsert current gateway identity
- append registration history
- return HTTP `2xx` on successful durable persistence
- Exit criteria:
- a gateway can register repeatedly without corrupting identity state
- registration events are queryable historically
- Implemented so far:
- added `POST /api/v1/gateways/register` in [server/index.ts](/home/diego/PyroNet/csp/server/index.ts)
- route now validates `application/octet-stream`, parses one `0x81` message, and persists gateway snapshot plus append-only registration history
- current gateway snapshot updates are guarded so older gateway timestamps do not overwrite newer state
- Planned files:
- [server/index.ts](/home/diego/PyroNet/csp/server/index.ts)
- [schema.sql](/home/diego/PyroNet/csp/schema.sql)

### Phase 4 - Durable Uplink Inbox

- Status: `done`
- Goal: persist every `0x82` envelope before application projection
- Scope:
- add `POST /api/v1/uplinks`
- accept one octet-stream envelope per request
- persist raw envelope bytes and parsed header metadata first
- deduplicate on `(gateway_id, uplink_id)`
- return a terminal `0x83` only after durable persistence and terminal classification
- Exit criteria:
- replay-safe ingest exists even before full packet projection is complete
- duplicate deliveries produce the same terminal result
- Implemented so far:
- added `POST /api/v1/uplinks` in [server/index.ts](/home/diego/PyroNet/csp/server/index.ts)
- valid `0x82` envelopes are parsed, stored durably in `gateway_uplinks`, and answered with a binary `0x83` durable-ingest receipt
- duplicate `(gateway_id, uplink_id)` deliveries reuse the stored terminal receipt and increment delivery-attempt tracking
- parse and validation failures with enough header information are persisted as rejected raw envelopes with terminal reject receipts and dead-letter rows
- adjusted [schema.sql](/home/diego/PyroNet/csp/schema.sql) so placeholder gateway rows and rejected raw envelopes can be stored without inventing trusted parsed fields
- Planned files:
- [server/index.ts](/home/diego/PyroNet/csp/server/index.ts)
- [schema.sql](/home/diego/PyroNet/csp/schema.sql)

### Phase 5 - Application Projection

- Status: `done`
- Goal: project persisted uplinks into the existing CSP domain model
- Scope:
- `0x01` -> devices, registrations, IPv6 history, current last-seen state
- `0x02` / `0x03` -> sensor readings, current device telemetry, alert-driving records
- `0x08` -> preferred-parent observation history and latest topology state
- attach gateway metadata and raw-payload metadata where appropriate
- keep projection idempotent relative to the raw envelope key
- Exit criteria:
- existing read APIs can operate on ingested backhaul data
- duplicate uplinks do not create duplicate domain records
- Implemented so far:
- valid `0x82` uplinks now project inside the ingest transaction before the terminal durable-ingest receipt is stored
- `0x01` projection updates `devices`, writes `device_registrations`, syncs `device_ipv6_history`, and captures registration-time preferred-parent observations
- `0x02` / `0x03` projection writes `sensor_readings`, updates latest device telemetry, and creates `alerts` plus `alert_events` for `0x03`
- `0x08` projection updates current preferred-parent state and writes append-only parent observation history
- added explicit uplink traceability from projected rows back to `gateway_uplinks`
- Planned files:
- [server/index.ts](/home/diego/PyroNet/csp/server/index.ts)
- [schema.sql](/home/diego/PyroNet/csp/schema.sql)

### Phase 6 - Receipt and Dead-Letter Semantics

- Status: `in_progress`
- Goal: make terminal outcomes explicit and auditable
- Scope:
- store terminal status for each uplink
- return consistent `0x83` for duplicate submissions
- persist permanent rejects with reason codes or operator-readable detail
- separate transient failures from permanent rejects cleanly
- Exit criteria:
- gateway retry behavior can rely on CSP terminal responses
- operators can inspect why a payload was rejected
- Implemented so far:
- parse-stage permanent rejects now use a stable reject-code taxonomy
- duplicate terminal rejects reuse the stored `0x83` and surface the same reject code in API response headers
- projection-stage semantic failures remain retryable rather than becoming terminal `0x83` rejects
- dead-letter and receipt metadata remain focused on parse/validation permanent rejects
- Planned files:
- [schema.sql](/home/diego/PyroNet/csp/schema.sql)
- [server/index.ts](/home/diego/PyroNet/csp/server/index.ts)

### Phase 7 - Read Model Alignment

- Status: `done`
- Goal: align existing API queries and history views with persisted ingest data
- Scope:
- verify dashboard/node/history/alert queries consume the projected records consistently
- ensure packet history is backed by actual ingested records and downlink events
- minimize assumptions that currently exist only for mocks or derived history
- Exit criteria:
- read APIs reflect the new persistence model without ad hoc translation gaps
- Implemented so far:
- added `0x08` / `parent_update` to shared packet-history type definitions
- packet history now includes persisted `device_parent_observations` rows for `0x08` parent updates
- node detail responses now expose current preferred parent and recent parent-observation history
- history-page filters now expose the persisted packet-code dimension instead of only direction/event/status
- mock backend and node-detail UI surfaces were aligned to the same response contract
- Planned files:
- [server/index.ts](/home/diego/PyroNet/csp/server/index.ts)
- [src/api/types.ts](/home/diego/PyroNet/csp/src/api/types.ts)

### Phase 8 - Verification and Operations

- Status: `not_started`
- Goal: verify persistence behavior under duplicate delivery, malformed input, and restart-safe ingest flows
- Scope:
- fixture-driven binary parser tests
- idempotency tests for duplicate uplinks
- tests for permanent reject vs transient failure behavior
- metrics/logging hooks for ingest success, duplicates, and rejects
- Exit criteria:
- persistence semantics are test-backed and observable
- Planned files:
- tests or validation harness to be added

## Change Log

- 2026-04-22: Created phased persistence implementation tracker.
- 2026-04-22: Began Phase 1 and added schema-level persistence tables for gateways, raw uplinks, terminal receipts, and dead-letter records.
- 2026-04-22: Began Phase 2 and added a standalone backhaul codec module for binary message parsing and `0x83` receipt encoding.
- 2026-04-22: Began Phase 3 and wired `POST /api/v1/gateways/register` to persist binary `0x81` gateway registrations.
- 2026-04-22: Completed Phase 4 route wiring for `POST /api/v1/uplinks`, including durable raw-envelope storage, duplicate receipt reuse, and binary `0x83` responses.
- 2026-04-22: Began Phase 5 by projecting `0x01`, `0x02`, `0x03`, and `0x08` uplinks into device, telemetry, alert, and parent-observation tables.
- 2026-04-22: Relaxed ingest validation and schema constraints to accept private/ULA IPv6 addresses for observed node and parent metadata.
- 2026-04-22: Began Phase 6 by normalizing permanent-reject taxonomy across parse and projection failures and surfacing stable reject codes on uplink responses.
- 2026-04-22: Adjusted Phase 6 behavior so projection-stage semantic failures remain retryable and only parse/validation failures produce terminal permanent rejects.
- 2026-04-22: Began Phase 7 by aligning packet history and node detail read models with persisted `0x08` parent-update observations.
- 2026-04-22: Closed Phase 7 for now after aligning packet history, node detail, and traffic-log filters with persisted parent-update data.

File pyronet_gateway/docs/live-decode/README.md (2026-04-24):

# PyroNet Live Decode Tool

This document covers only the passive live decoder for PyroNet packets:

```bash
python3 -m pyronet_gateway.live_decode
```

## Purpose

`pyronet_gateway.live_decode` passively sniffs IPv6 UDP traffic on a Linux
interface, parses CoAP traffic on the configured PyroNet port, and decodes the
PyroNet packet payload into human-readable fields.

It is intended for:

- Watching live PyroNet uplinks from nodes
- Watching live PyroNet downlinks sent back to nodes
- Watching backhaul queue and delivery state for accepted uplinks
- Verifying packet contents without manually unpacking binary payloads

It does not bind the gateway UDP port, so it can run alongside the gateway
service.

## What It Decodes

### Uplink packets

The tool decodes CoAP `POST` requests to the uplink resource, normally
`/uplink`.

Supported PyroNet uplink packet types:

- `0x01` Registration
- `0x02` Sensor report
- `0x03` Sensor alert
- `0x08` Parent update

Special case:

- `0x07` Neighbor alert is recognized but shown as ignored by the gateway

### Downlink packets

The tool decodes CoAP `POST` requests to the downlink resource, normally
`/downlink`.

Supported PyroNet downlink packet types:

- `0x04` Neighbor table update
- `0x05` Time sync
- `0x06` Config update

### Backhaul events

With `--show-backhaul`, the tool also tails the gateway SQLite database and
shows uplink lifecycle events as the retry worker processes them.

Supported backhaul events:

- `backhaul enqueue`
- `backhaul retry`
- `backhaul delivered`
- `backhaul dead-letter`

This is derived from the local outbox and dead-letter tables, not by decoding
raw HTTP packets on the wire.

## Requirements

- Linux
- Root privileges for passive packet sniffing
- Python 3
- The `pyronet_gateway` source tree

The decoder uses raw sockets via `AF_PACKET`, so it usually must be run with
`sudo`.

## Basic Usage

From the `pyronet_gateway/` directory:

```bash
sudo python3 -m pyronet_gateway.live_decode --config ./config.example.toml
```

Equivalent `make` target:

```bash
sudo make live-decode
```

By default this:

- Uses `./config.example.toml`
- Sniffs `tun0`
- Uses the CoAP port from the config file
- Uses the configured uplink and downlink resource paths
- Shows recognized PyroNet traffic only
- Shows ACKs
- Shows backhaul queue/retry/delivery state from the gateway database

If you run the Python module directly, add `--show-backhaul` to show backhaul queue state from the gateway database:

```bash
sudo python3 -m pyronet_gateway.live_decode \
  --config ./config.example.toml \
  --show-backhaul
```

If you are not passing `--config`, provide the SQLite database path explicitly:

```bash
sudo python3 -m pyronet_gateway.live_decode \
  --port 5683 \
  --uplink-resource /uplink \
  --downlink-resource /downlink \
  --show-backhaul \
  --db-path ./pyronet-gateway.sqlite3
```

## Common Options

### Show ACKs With Direct Python

```bash
sudo python3 -m pyronet_gateway.live_decode \
  --config ./config.example.toml \
  --show-acks
```

The `make` target enables ACKs by default:

```bash
sudo make live-decode
```

### Use a different interface

```bash
sudo python3 -m pyronet_gateway.live_decode \
  --config ./config.example.toml \
  --interface tun0
```

### Override the CoAP port or resource paths

```bash
sudo python3 -m pyronet_gateway.live_decode \
  --port 5683 \
  --uplink-resource /uplink \
  --downlink-resource /downlink
```

### Show other CoAP traffic on the same port

```bash
sudo python3 -m pyronet_gateway.live_decode \
  --config ./config.example.toml \
  --show-non-pyronet
```

## Example Output

Registration uplink:

```text
12:34:56.123 fd12:3456::10:61616 -> fd12:3456::1:5683 uplink code=0.02 path=/uplink token=01020304 type=REGISTRATION node=1001 ver=1 lat=39.0000 lon=-86.0000 fw=0x0102 batt=88% parent=fd12:3456::2
```

Sensor alert uplink:

```text
12:34:58.440 fd12:3456::10:61616 -> fd12:3456::1:5683 uplink code=0.02 path=/uplink token=01020304 type=SENSOR_ALERT node=1002 ver=1 ts=123456 risk=4 temp_raw=2450 humidity_raw=5000 voc_iaq=123 pm25=55 batt=90%
```

Neighbor-table downlink:

```text
12:35:01.008 fd12:3456::1:40000 -> fd12:3456::10:5683 downlink code=0.02 path=/downlink token=01020304 type=NN_TABLE target=1003 ver=1 count=2 neighbors=['fd12:3456::10', 'fd12:3456::11']
```

Backhaul enqueue:

```text
12:35:02.000 backhaul enqueue uplink_id=7 gateway=77 src=fd12:3456::10 type=REGISTRATION node=1001 ver=1 lat=39.0000 lon=-86.0000 fw=0x0102 batt=88% parent=fd12:3456::2
```

Backhaul retry:

```text
12:35:04.000 backhaul retry uplink_id=7 attempts=1 next_at=12:35:09 error=HTTP 503
```

Backhaul delivery:

```text
12:35:05.000 backhaul delivered uplink_id=7 attempts=1 gateway=77 src=fd12:3456::10 type=REGISTRATION node=1001 ver=1 lat=39.0000 lon=-86.0000 fw=0x0102 batt=88% parent=fd12:3456::2
```

## Field Notes

- `temp_raw`, `humidity_raw`, and similar values are shown exactly as encoded in
  the current PyroNet packet format
- The decoder does not apply any extra engineering-unit scaling beyond what is
  explicitly encoded in the packet structures
- `parent` shows `-` when the parent IPv6 field is all zeros
- Backhaul lines reflect durable queue state from SQLite and may appear slightly
  after the corresponding uplink packet line

## What The Tool Does Not Do

- It does not decode Wi-SUN MAC fields
- It does not decode raw 802.15.4 frames
- It does not read packets from `pcapng`
- It does not modify or inject traffic
- It does not persist anything to the gateway database
- It does not decode raw HTTP traffic to the remote backhaul service

This tool is specifically for decoding PyroNet CoAP payloads observed on the
wire plus reporting local backhaul queue state.

## Troubleshooting

### `live decode needs root privileges`

Run with `sudo`.

### `failed to open interface`

Check that the interface exists and is up:

```bash
ip link show tun0
```

### No output appears

Check:

- The gateway and nodes are actively sending traffic
- You are sniffing the correct interface
- The correct CoAP port is configured
- The resource paths match the runtime configuration

### Only ACKs are visible

Enable:

```bash
--show-acks
```

If you want to also see unrelated CoAP traffic on the same port:

```bash
--show-non-pyronet
```

## Source

Implementation:

- [pyronet_gateway/live_decode.py](/home/admin/border_router/pyronet_gateway/pyronet_gateway/live_decode.py:1)

Related protocol definitions:

- [pyronet_gateway/protocol/node_packets.py](/home/admin/border_router/pyronet_gateway/pyronet_gateway/protocol/node_packets.py:1)
- [pyronet_gateway/downlink_packet_codec.py](/home/admin/border_router/pyronet_gateway/pyronet_gateway/downlink_packet_codec.py:1)
- [pyronet_gateway/coap_intake.py](/home/admin/border_router/pyronet_gateway/pyronet_gateway/coap_intake.py:1)

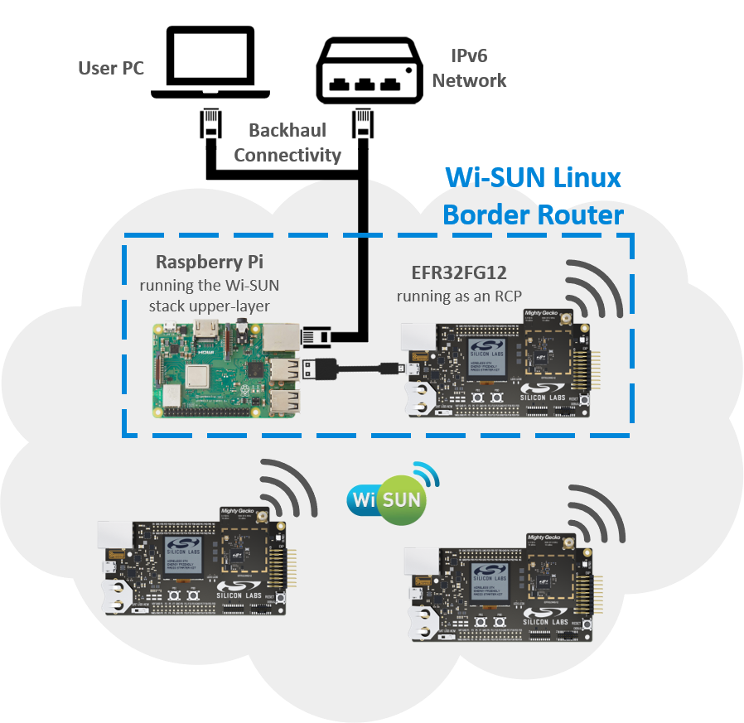
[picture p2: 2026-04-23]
firmware/wisun_rcp/doc/readme_img1.png

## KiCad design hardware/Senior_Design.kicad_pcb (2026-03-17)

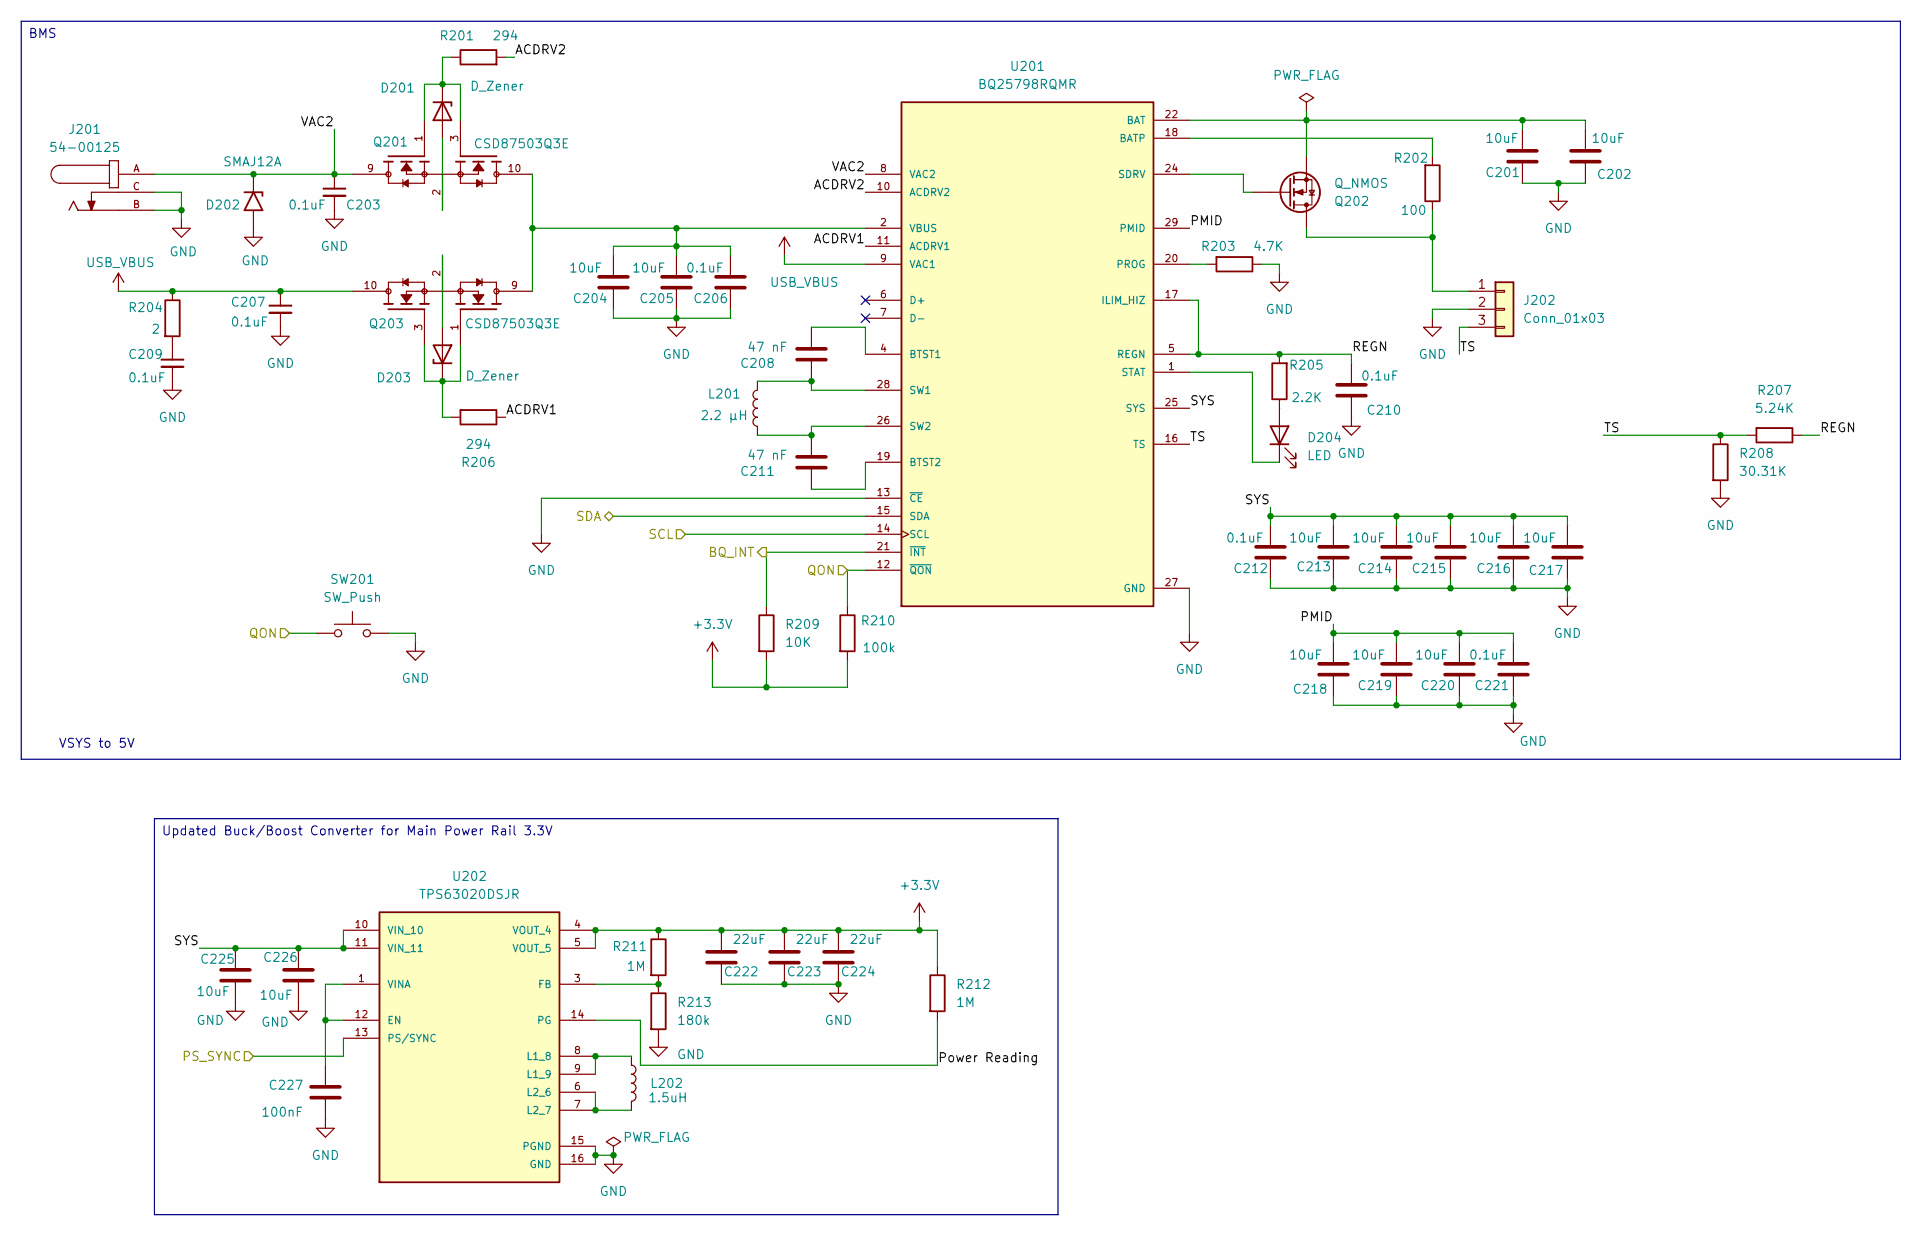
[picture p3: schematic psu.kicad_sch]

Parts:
C201, C202, C225, C226: 10uF; C_0603_1608Metric
C203, C207, C209: 0.1uF; C_0805_2012Metric
C204, C205, C213, C214, C215, C216, C217, C218, C219, C220: 10uF; C_0805_2012Metric
C206, C212, C221: 0.1uF; C_0402_1005Metric
C208, C211: 47 nF; C_0603_1608Metric
C210: 0.1uF; C_0603_1608Metric
C222, C223, C224: 22uF; C_0603_1608Metric
C227: 100nF; C_0603_1608Metric
D201, D203: D_Zener; D_SOD-123
D202: SMAJ12A; D_SMA
D204: LED; LED_0805_2012Metric
J201: 54-00125; TENSILITY_54-00125; PARTREV A; DigiKey_Part_Number 839-54-00125-ND
J202: Conn_01x03; JST_PH_S3B-PH-K_1x03_P2.00mm_Horizontal
L201: 2.2 µH; L_Bourns_SRP7028A_7.3x6.6mm
L202: 1.5uH; L_Wuerth_MAPI-4020
Q201, Q203: CSD87503Q3E; TRANS_CSD87503Q3ET; PARTREV SEPTEMBER 2017; DigiKey_Part_Number 296-47497-1-ND
Q202: Q_NMOS; SOT-23_Handsoldering
R201, R206: 294; R_0805_2012Metric
R202: 100; R_0805_2012Metric
R203: 4.7K; R_0805_2012Metric
R204: 2; R_0805_2012Metric
R205: 2.2K; R_0805_2012Metric
R207: 5.24K; R_0805_2012Metric
R208: 30.31K; R_0805_2012Metric
R209: 10K; R_0805_2012Metric
R210: 100k; R_0805_2012Metric
R211: 1M; R_0603_1608Metric
R212: 1M; R_0805_2012Metric
R213: 180k; R_0603_1608Metric
SW201: SW_Push; SW_SPST_TL3305A
U201: BQ25798RQMR; IC_BQ25798RQMR; PARTREV B
U202: TPS63020DSJR; IC_TPS63020DSJR

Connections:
+3.3V: C222.2, C223.2, C224.2, R209.2, R210.2, R211.1, R212.1, U202.4 (VOUT_4), U202.5 (VOUT_5); also elsewhere on the board
/BME 688 and SPS30/SCL: U201.14 (SCL); also elsewhere on the board
/BME 688 and SPS30/SDA: U201.15 (SDA); also elsewhere on the board
/BMS/ACDRV1: R206.1, U201.11 (ACDRV1)
/BMS/ACDRV2: R201.2, U201.10 (ACDRV2)
/BMS/BQ_INT: R209.1, U201.21 (~INT); also elsewhere on the board
/BMS/PMID: C218.1, C219.1, C220.1, C221.1, U201.29 (PMID)
/BMS/PS_SYNC: U202.13 (PS/SYNC); also elsewhere on the board
/BMS/Power Reading: R212.2, U202.14 (PG)
/BMS/QON: R210.1, SW201.1, U201.12 (~QON); also elsewhere on the board
/BMS/REGN: C210.1, R205.2, R207.1, U201.5 (REGN), U201.17 (ILIM_HIZ)
/BMS/SYS: C212.1, C213.1, C214.1, C215.1, C216.1, C217.1, C225.1, C226.1, U201.25 (SYS), U202.10 (VIN_10), U202.11 (VIN_11)
/BMS/TS: J202.3, R207.2, R208.1, U201.16 (TS)
/BMS/VAC2: C203.1, D202.1 (A1), J201.A, Q201.9, Q201.9.1, Q201.9.2, U201.8 (VAC2)
BAT: C201.1, C202.1, Q202.2 (S), U201.22 (BAT), U201.23 (BAT)
GND: C201.2, C202.2, C203.2, C204.2, C205.2, C206.2, C207.2, C209.2, C210.2, C212.2, C213.2, C214.2, C215.2, C216.2, C217.2, C218.2, C219.2, C220.2, C221.2, C222.1, C223.1, C224.1, C225.2, C226.2, C227.2, D202.2 (A2), J201.B, J201.C, J202.2, R203.1, R208.2, R213.2, SW201.2, U201.13 (~CE), U201.27 (GND), U202.2 (GND), U202.15 (PGND), U202.16 (GND), U202.17 (GND), U202.18 (GND), U202.19 (GND), U202.20 (GND), U202.21 (GND), U202.22 (GND), U202.23 (GND), U202.24 (GND), U202.25 (GND), U202.26 (GND), U202.27 (GND), U202.28 (GND), U202.29 (GND), U202.30 (GND); also elsewhere on the board
unnamed: C204.1, C205.1, C206.1, Q201.10, Q201.10.1, Q201.10.2, Q203.9, Q203.9.1, Q203.9.2, U201.2 (VBUS), U201.3 (VBUS)
unnamed: C209.1, R204.2
unnamed: D201.2 (A), Q201.2, Q201.4
unnamed: D201.1 (K), Q201.1, Q201.3, R201.1
unnamed: D203.2 (A), Q203.2, Q203.4
unnamed: D203.1 (K), Q203.1, Q203.3, R206.2
unnamed: D204.2 (A), R205.1
unnamed: D204.1 (K), U201.1 (STAT)
unnamed: J202.1, Q202.1 (D), R202.1
unnamed: Q202.3 (G), U201.24 (SDRV)
unnamed: R202.2, U201.18 (BATP)
unnamed: C208.1, U201.4 (BTST1)
unnamed: C211.2, U201.19 (BTST2)
unnamed: R203.2, U201.20 (PROG)
unnamed: C208.2, L201.2, U201.28 (SW1)
unnamed: C211.1, L201.1, U201.26 (SW2)
unnamed: C227.1, U202.1 (VINA), U202.12 (EN)
unnamed: R211.2, R213.1, U202.3 (FB)
unnamed: L202.1, U202.8 (L1_8), U202.9 (L1_9)
unnamed: L202.2, U202.6 (L2_6), U202.7 (L2_7)
USB_VBUS: C207.1, Q203.10, Q203.10.1, Q203.10.2, R204.1, U201.9 (VAC1); also elsewhere on the board

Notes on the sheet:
VSYS to 5V
Updated Buck/Boost Converter for Main Power Rail 3.3V
BMS

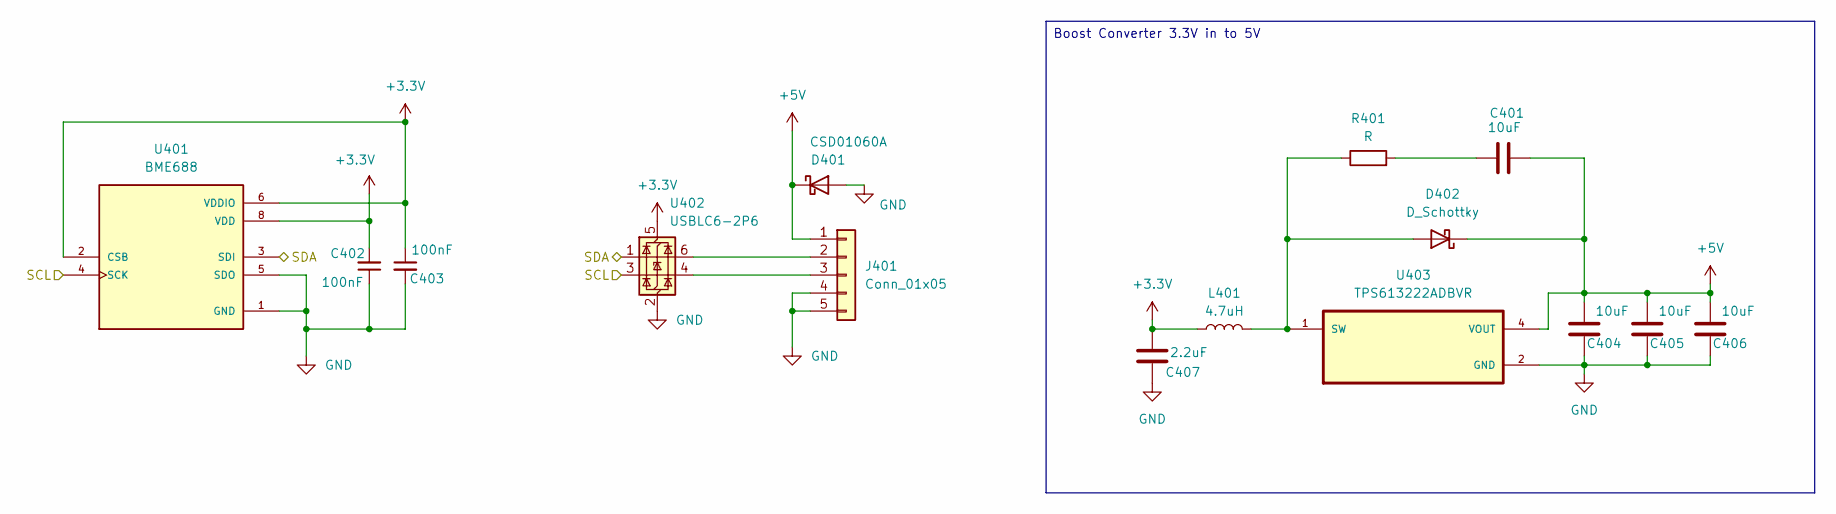
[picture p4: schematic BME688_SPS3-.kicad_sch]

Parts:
C401: 10uF; C_0402_1005Metric
C402, C403: 100nF; C_0805_2012Metric
C404, C405, C406: 10uF; C_0603_1608Metric
C407: 2.2uF; C_0603_1608Metric
D401: CSD01060A; D_SOD-123
D402: D_Schottky; D_0805_2012Metric
J401: Conn_01x05; JST_ZH_B5B-ZR_1x05_P1.50mm_Vertical
L401: 4.7uH; L_1008_2520Metric
R401: R; R_0402_1005Metric
U401: BME688; IC_BME688; PARTREV 1.0
U402: USBLC6-2P6; SOT-666
U403: TPS613222ADBVR; SOT95P280X145-5N; DigiKey_Part_Number 296-50503-1-ND

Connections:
+3.3V: C402.2, C403.1, C407.2, L401.1, U401.2 (CSB), U401.6 (VDDIO), U401.8 (VDD), U402.5 (VBUS); also elsewhere on the board
+5V: C401.1, C404.2, C405.2, C406.2, D401.1 (K), D402.1 (K), J401.1, U403.4 (VOUT)
/BME 688 and SPS30/SCL: U401.4 (SCK), U402.3 (I/O2); also elsewhere on the board
/BME 688 and SPS30/SDA: U401.3 (SDI), U402.1 (I/O1); also elsewhere on the board
GND: C402.1, C403.2, C404.1, C405.1, C406.1, C407.1, D401.2 (A), J401.4, J401.5, U401.1 (GND), U401.5 (SDO), U401.7 (GND), U402.2 (GND), U403.2 (GND); also elsewhere on the board
unnamed: C401.2, R401.2
unnamed: D402.2 (A), L401.2, R401.1, U403.1 (SW)
unnamed: J401.2, U402.6 (I/O1)
unnamed: J401.3, U402.4 (I/O2)

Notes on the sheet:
Boost Converter 3.3V in to 5V

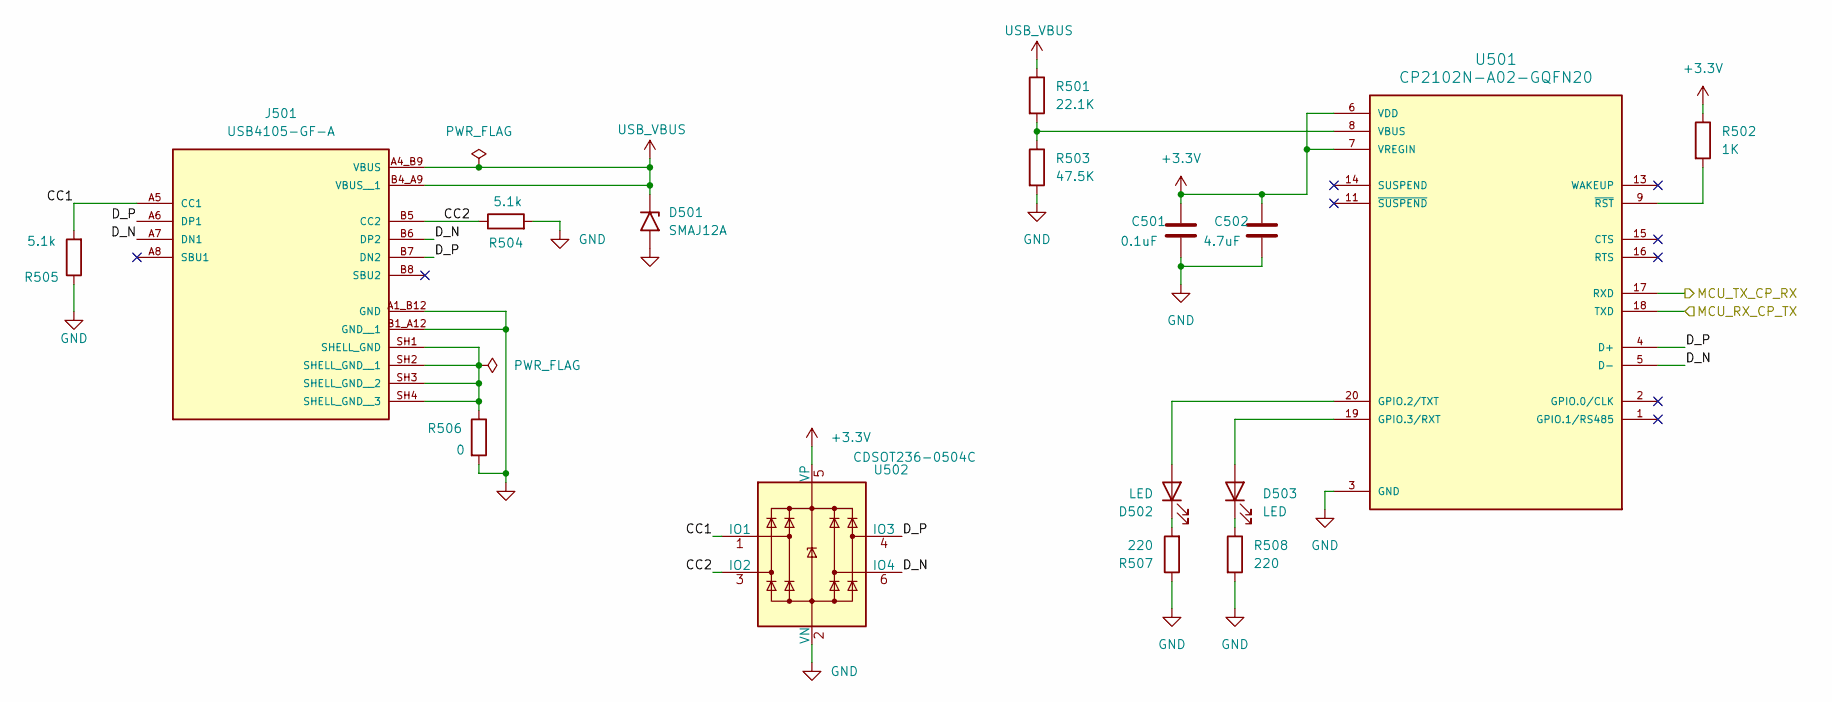
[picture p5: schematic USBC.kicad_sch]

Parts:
C501: 0.1uF; C_0603_1608Metric
C502: 4.7uF; C_0603_1608Metric
D501: SMAJ12A; D_SMA
D502, D503: LED; LED_0805_2012Metric
J501: USB4105-GF-A; GCT_USB4105-GF-A; PARTREV B4
R501: 22.1K; R_0805_2012Metric
R502: 1K; R_0805_2012Metric
R503: 47.5K; R_0805_2012Metric
R504, R505: 5.1k; R_0805_2012Metric
R506: 0; R_0805_2012Metric
R507, R508: 220; R_0805_2012Metric
U501: CP2102N-A02-GQFN20; SILABS_CP2102N-A02-GQFN20R; PARTREV 1.3
U502: CDSOT236-0504C; SOT-23-6

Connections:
+3.3V: C501.1, C502.1, R502.1, U501.6 (VDD), U501.7 (VREGIN), U502.5 (VP); also elsewhere on the board
/MCU/MCU_RX_CP_TX: U501.18 (TXD); also elsewhere on the board
/MCU/MCU_TX_CP_RX: U501.17 (RXD); also elsewhere on the board
/USB-C/CC1: J501.A5 (CC1), R505.2, U502.1 (IO1)
/USB-C/CC2: J501.B5 (CC2), R504.1, U502.3 (IO2)
/USB-C/D_N: J501.A7 (DN1), J501.B6 (DP2), U501.5 (D-), U502.6 (IO4)
/USB-C/D_P: J501.A6 (DP1), J501.B7 (DN2), U501.4 (D+), U502.4 (IO3)
GND: C501.2, C502.2, D501.2 (A2), J501.A1_B12 (GND), J501.B1_A12 (GND__1), R503.2, R504.2, R505.1, R506.2, R507.1, R508.2, U501.3 (GND), U501.12 (GND), U501.21 (GND), U502.2 (VN); also elsewhere on the board
unnamed: D502.2 (A), U501.20 (GPIO.2/TXT)
unnamed: D502.1 (K), R507.2
unnamed: D503.2 (A), U501.19 (GPIO.3/RXT)
unnamed: D503.1 (K), R508.1
unnamed: J501.SH1 (SHELL_GND), J501.SH2 (SHELL_GND__1), J501.SH3 (SHELL_GND__2), J501.SH4 (SHELL_GND__3), R506.1
unnamed: R501.2, R503.1, U501.8 (VBUS)
unnamed: R502.2, U501.9 (~RST)
USB_VBUS: D501.1 (A1), J501.A4_B9 (VBUS), J501.B4_A9 (VBUS__1), R501.1; also elsewhere on the board

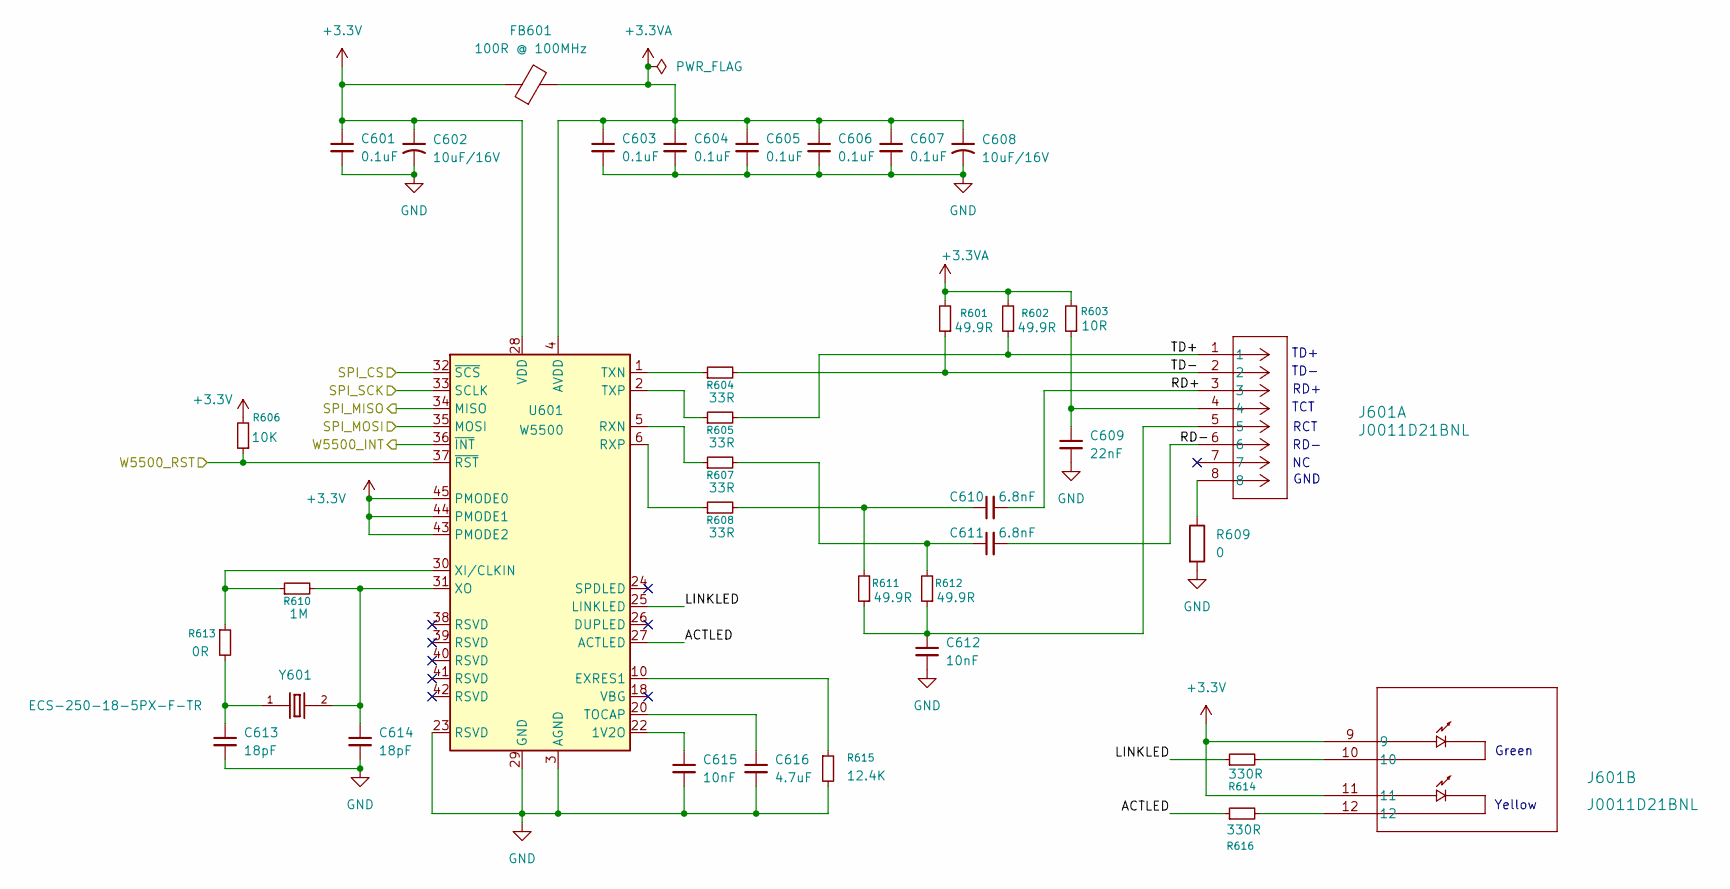
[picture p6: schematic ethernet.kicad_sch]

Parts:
C601, C603, C604, C605, C606, C607: 0.1uF; C_0603_1608Metric
C602, C608: 10uF/16V; C_0603_1608Metric
C609: 22nF; C_0805_2012Metric
C610, C611: 6.8nF; C_0805_2012Metric
C612, C615: 10nF; C_0805_2012Metric
C613, C614: 18pF; C_0805_2012Metric
C616: 4.7uF; C_0805_2012Metric
FB601: 100R @ 100MHz; R_0603_1608Metric
J601: J0011D21BNL; CONN_J0011D21B_PUL
R601, R602, R611, R612: 49.9R; R_0805_2012Metric
R603: 10R; R_0805_2012Metric
R604, R605, R607, R608: 33R; R_0805_2012Metric
R606: 10K; R_0603_1608Metric
R609: 0; R_0805_2012Metric
R610: 1M; R_0805_2012Metric
R613: 0R; R_0805_2012Metric
R614, R616: 330R; R_0805_2012Metric
R615: 12.4K; R_0805_2012Metric
U601: W5500; LQFP-48_7x7mm_P0.5mm
Y601: ECS-250-18-5PX-F-TR; XTAL_ECS-250-18-5PX-F-TR; PARTREV 2017; DigiKey_Part_Number XC1305CT-ND

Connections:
+3.3V: C601.1, C602.1, FB601.1, J601.9, J601.11, R606.2, U601.28 (VDD), U601.43 (PMODE2), U601.44 (PMODE1), U601.45 (PMODE0); also elsewhere on the board
+3.3VA: C603.1, C604.1, C605.1, C606.1, C607.1, C608.1, FB601.2, R601.2, R602.2, R603.2, U601.4 (AVDD), U601.8 (AVDD), U601.11 (AVDD), U601.15 (AVDD), U601.17 (AVDD), U601.21 (AVDD)
/Ethernet/ACTLED: R616.1, U601.27 (ACTLED)
/Ethernet/LINKLED: R614.1, U601.25 (LINKLED)
/Ethernet/RD+: C610.2, J601.3
/Ethernet/RD-: C611.2, J601.6
/Ethernet/SPI_CS: U601.32 (~SCS); also elsewhere on the board
/Ethernet/SPI_MISO: U601.34 (MISO); also elsewhere on the board
/Ethernet/SPI_MOSI: U601.35 (MOSI); also elsewhere on the board
/Ethernet/SPI_SCK: U601.33 (SCLK); also elsewhere on the board
/Ethernet/TD+: J601.1, R602.1, R605.2
/Ethernet/TD-: J601.2, R601.1, R604.2
/Ethernet/W5500_INT: U601.36 (~INT); also elsewhere on the board
/Ethernet/W5500_RST: R606.1, U601.37 (~RST); also elsewhere on the board
GND: C601.2, C602.2, C603.2, C604.2, C605.2, C606.2, C607.2, C608.2, C609.2, C612.2, C613.2, C614.2, C615.2, C616.2, R609.2, R615.2, U601.3 (AGND), U601.9 (AGND), U601.14 (AGND), U601.16 (AGND), U601.19 (AGND), U601.23 (RSVD), U601.29 (GND), U601.48 (AGND); also elsewhere on the board
unnamed: C609.1, J601.4, R603.1
unnamed: C610.1, R608.2, R611.2
unnamed: C611.1, R607.2, R612.2
unnamed: C612.1, J601.5, R611.1, R612.1
unnamed: C613.1, R613.2, Y601.1
unnamed: J601.8, R609.1
unnamed: J601.10, R614.2
unnamed: J601.12, R616.2
unnamed: C615.1, U601.22 (1V2O)
unnamed: R615.1, U601.10 (EXRES1)
unnamed: R607.1, U601.5 (RXN)
unnamed: R608.1, U601.6 (RXP)
unnamed: C616.1, U601.20 (TOCAP)
unnamed: R604.1, U601.1 (TXN)
unnamed: R605.1, U601.2 (TXP)
unnamed: R610.1, R613.1, U601.30 (XI/CLKIN)
unnamed: C614.1, R610.2, U601.31 (XO), Y601.2

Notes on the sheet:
TD+
GND
TD-
TCT
Green
RCT
Yellow
RD+
RD-

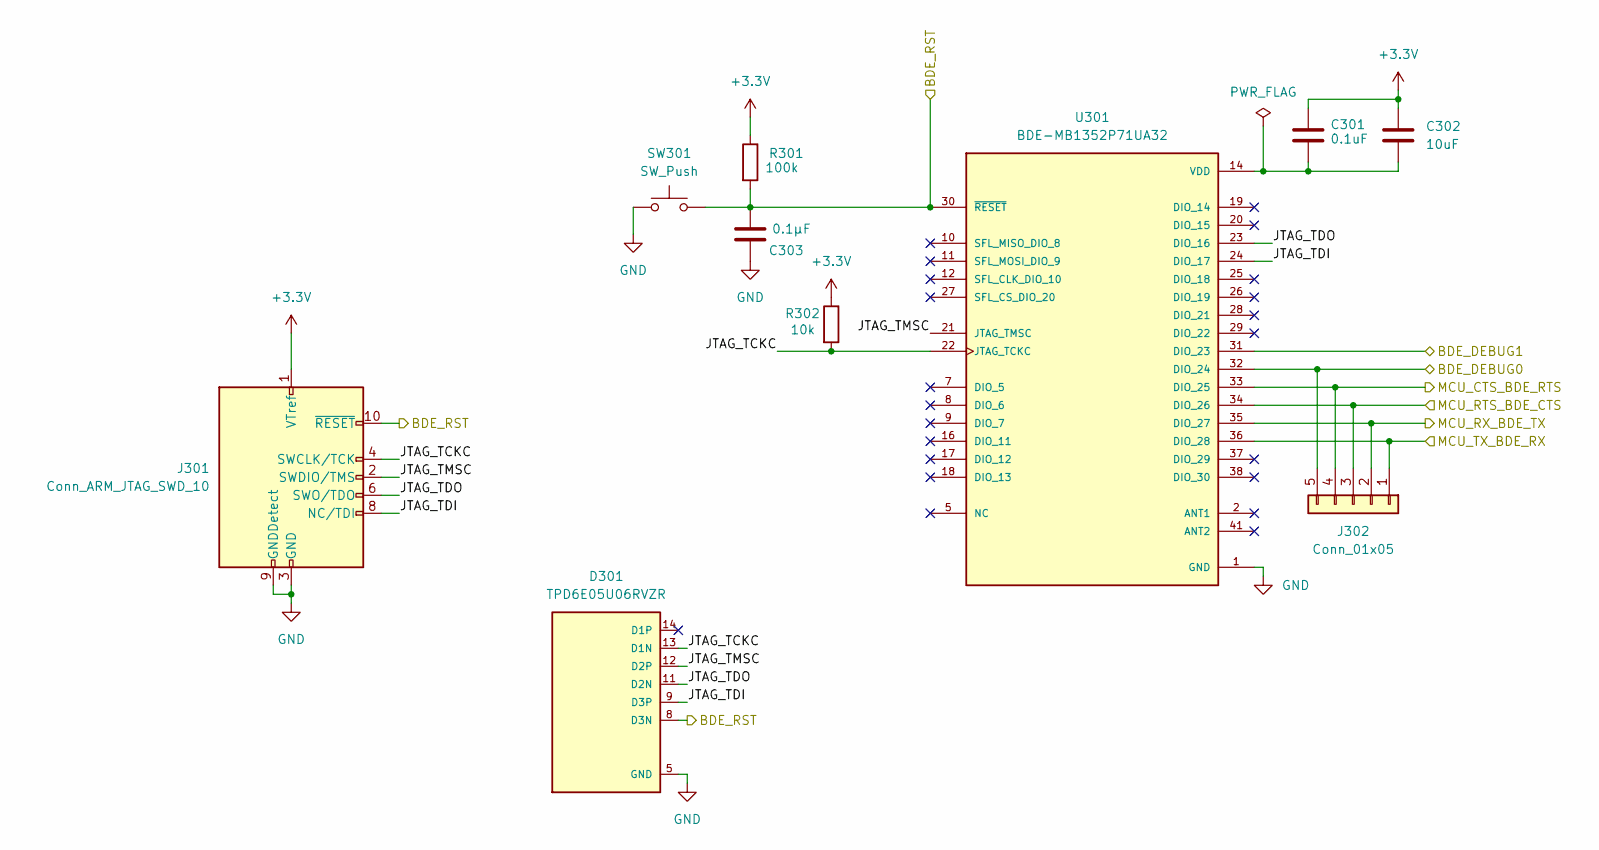
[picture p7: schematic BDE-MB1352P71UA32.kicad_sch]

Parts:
C301: 0.1uF; C_0805_2012Metric
C302: 10uF; C_0805_2012Metric
C303: 0.1µF; C_0805_2012Metric
D301: TPD6E05U06RVZR; SON50P135X350X55-14N; PARTREV L; DigiKey_Part_Number 296-39349-1-ND
J301: Conn_ARM_JTAG_SWD_10; PinHeader_2x05_P1.27mm_Vertical_SMD
J302: Conn_01x05; PinHeader_1x05_P2.54mm_Vertical
R301: 100k; R_0805_2012Metric
R302: 10k; R_0805_2012Metric
SW301: SW_Push; SW_SPST_TL3305A
U301: BDE-MB1352P71UA32; XCVR_BDE-MB1352P71UA32_1.03; PARTREV V1.1

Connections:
+3.3V: C301.1, C302.1, J301.1 (VTref), R301.1, R302.1; also elsewhere on the board
/MCU/BDE_DEBUG0: J302.5, U301.32 (DIO_24); also elsewhere on the board
/MCU/BDE_DEBUG1: U301.31 (DIO_23); also elsewhere on the board
/MCU/BDE_RST: C303.1, D301.8 (D3N), J301.10 (~RESET), R301.2, SW301.2, U301.30 (~RESET); also elsewhere on the board
/MCU/MCU_CTS_BDE_RTS: J302.4, U301.33 (DIO_25); also elsewhere on the board
/MCU/MCU_RTS_BDE_CTS: J302.3, U301.34 (DIO_26); also elsewhere on the board
/MCU/MCU_RX_BDE_TX: J302.1, U301.36 (DIO_28); also elsewhere on the board
/MCU/MCU_TX_BDE_RX: J302.2, U301.35 (DIO_27); also elsewhere on the board
/Wi-SUN Module/JTAG_TCKC: D301.13 (D1N), J301.4 (SWCLK/TCK), R302.2, U301.22 (JTAG_TCKC)
/Wi-SUN Module/JTAG_TDI: D301.9 (D3P), J301.8 (NC/TDI), U301.24 (DIO_17)
/Wi-SUN Module/JTAG_TDO: D301.11 (D2N), J301.6 (SWO/TDO), U301.23 (DIO_16)
/Wi-SUN Module/JTAG_TMSC: D301.12 (D2P), J301.2 (SWDIO/TMS), U301.21 (JTAG_TMSC)
GND: C303.2, D301.5 (GND), D301.10 (GND), J301.3 (GND), J301.5 (GND), J301.9 (GNDDetect), SW301.1, U301.1 (GND), U301.3 (GND), U301.4 (GND), U301.13 (GND), U301.39 (GND), U301.40 (GND), U301.42 (GND); also elsewhere on the board
VDD: C301.2, C302.2, U301.14 (VDD), U301.15 (VDD)

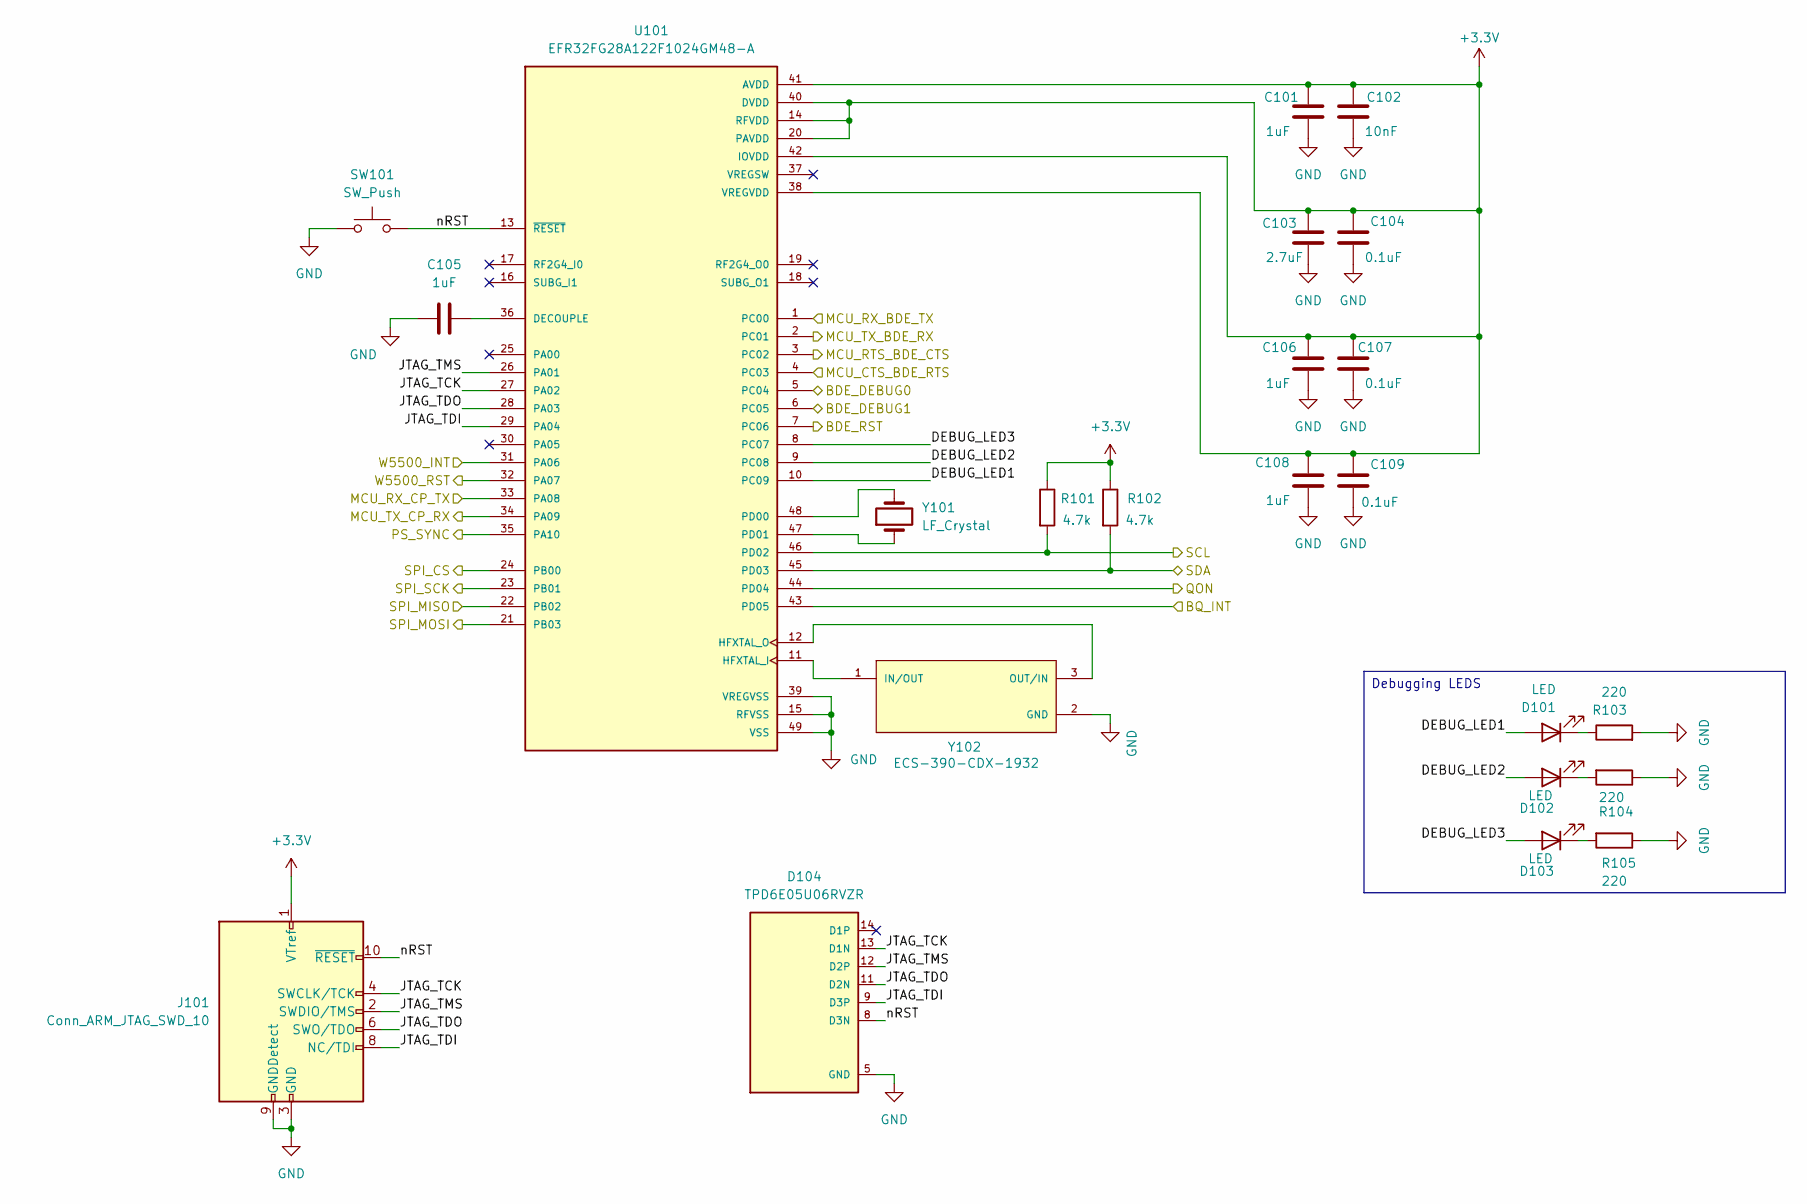
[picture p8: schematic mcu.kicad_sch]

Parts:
C101, C106, C108: 1uF; C_0603_1608Metric
C102: 10nF; C_0603_1608Metric
C103: 2.7uF; C_0603_1608Metric
C104, C107, C109: 0.1uF; C_0603_1608Metric
C105: 1uF; C_0805_2012Metric
D101, D102, D103: LED; LED_0805_2012Metric
D104: TPD6E05U06RVZR; SON50P135X350X55-14N; PARTREV L; DigiKey_Part_Number 296-39349-1-ND
J101: Conn_ARM_JTAG_SWD_10; PinHeader_2x05_P1.27mm_Vertical_SMD
R101, R102: 4.7k; R_0805_2012Metric
R103, R104, R105: 220; R_0805_2012Metric
SW101: SW_Push; SW_SPST_TL3305A
U101: EFR32FG28A122F1024GM48-A; QFN40P600X600X90-49N; PARTREV 1.1
Y101: LF_Crystal; Crystal_SMD_3215-2Pin_3.2x1.5mm
Y102: ECS-390-CDX-1932; XTAL_ECS-390-CDX-1932

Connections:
+3.3V: C101.1, C102.1, C103.1, C104.1, C106.1, C107.1, C108.1, C109.1, J101.1 (VTref), R101.1, R102.1, U101.14 (RFVDD), U101.20 (PAVDD), U101.38 (VREGVDD), U101.40 (DVDD), U101.41 (AVDD), U101.42 (IOVDD); also elsewhere on the board
/BME 688 and SPS30/SCL: R101.2, U101.46 (PD02); also elsewhere on the board
/BME 688 and SPS30/SDA: R102.2, U101.45 (PD03); also elsewhere on the board
/BMS/BQ_INT: U101.43 (PD05); also elsewhere on the board
/BMS/PS_SYNC: U101.35 (PA10); also elsewhere on the board
/BMS/QON: U101.44 (PD04); also elsewhere on the board
/Ethernet/SPI_CS: U101.24 (PB00); also elsewhere on the board
/Ethernet/SPI_MISO: U101.22 (PB02); also elsewhere on the board
/Ethernet/SPI_MOSI: U101.21 (PB03); also elsewhere on the board
/Ethernet/SPI_SCK: U101.23 (PB01); also elsewhere on the board
/Ethernet/W5500_INT: U101.31 (PA06); also elsewhere on the board
/Ethernet/W5500_RST: U101.32 (PA07); also elsewhere on the board
/MCU/BDE_DEBUG0: U101.5 (PC04); also elsewhere on the board
/MCU/BDE_DEBUG1: U101.6 (PC05); also elsewhere on the board
/MCU/BDE_RST: U101.7 (PC06); also elsewhere on the board
/MCU/DEBUG_LED1: D101.2 (A), U101.10 (PC09)
/MCU/DEBUG_LED2: D102.2 (A), U101.9 (PC08)
/MCU/DEBUG_LED3: D103.2 (A), U101.8 (PC07)
/MCU/JTAG_TCK: D104.13 (D1N), J101.4 (SWCLK/TCK), U101.27 (PA02)
/MCU/JTAG_TDI: D104.9 (D3P), J101.8 (NC/TDI), U101.29 (PA04)
/MCU/JTAG_TDO: D104.11 (D2N), J101.6 (SWO/TDO), U101.28 (PA03)
/MCU/JTAG_TMS: D104.12 (D2P), J101.2 (SWDIO/TMS), U101.26 (PA01)
/MCU/MCU_CTS_BDE_RTS: U101.4 (PC03); also elsewhere on the board
/MCU/MCU_RTS_BDE_CTS: U101.3 (PC02); also elsewhere on the board
/MCU/MCU_RX_BDE_TX: U101.1 (PC00); also elsewhere on the board
/MCU/MCU_RX_CP_TX: U101.33 (PA08); also elsewhere on the board
/MCU/MCU_TX_BDE_RX: U101.2 (PC01); also elsewhere on the board
/MCU/MCU_TX_CP_RX: U101.34 (PA09); also elsewhere on the board
/MCU/nRST: D104.8 (D3N), J101.10 (~RESET), SW101.2, U101.13 (~RESET)
GND: C101.2, C102.2, C103.2, C104.2, C105.1, C106.2, C107.2, C108.2, C109.2, D104.5 (GND), D104.10 (GND), J101.3 (GND), J101.5 (GND), J101.9 (GNDDetect), R103.2, R104.1, R105.1, SW101.1, U101.15 (RFVSS), U101.39 (VREGVSS), U101.49 (VSS), Y102.2 (GND), Y102.4 (GND__1); also elsewhere on the board
unnamed: D101.1 (K), R103.1
unnamed: D102.1 (K), R104.2
unnamed: D103.1 (K), R105.2
unnamed: C105.2, U101.36 (DECOUPLE)
unnamed: U101.11 (HFXTAL_I), Y102.1 (IN/OUT)
unnamed: U101.12 (HFXTAL_O), Y102.3 (OUT/IN)
unnamed: U101.48 (PD00), Y101.2
unnamed: U101.47 (PD01), Y101.1

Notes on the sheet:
Debugging LEDS

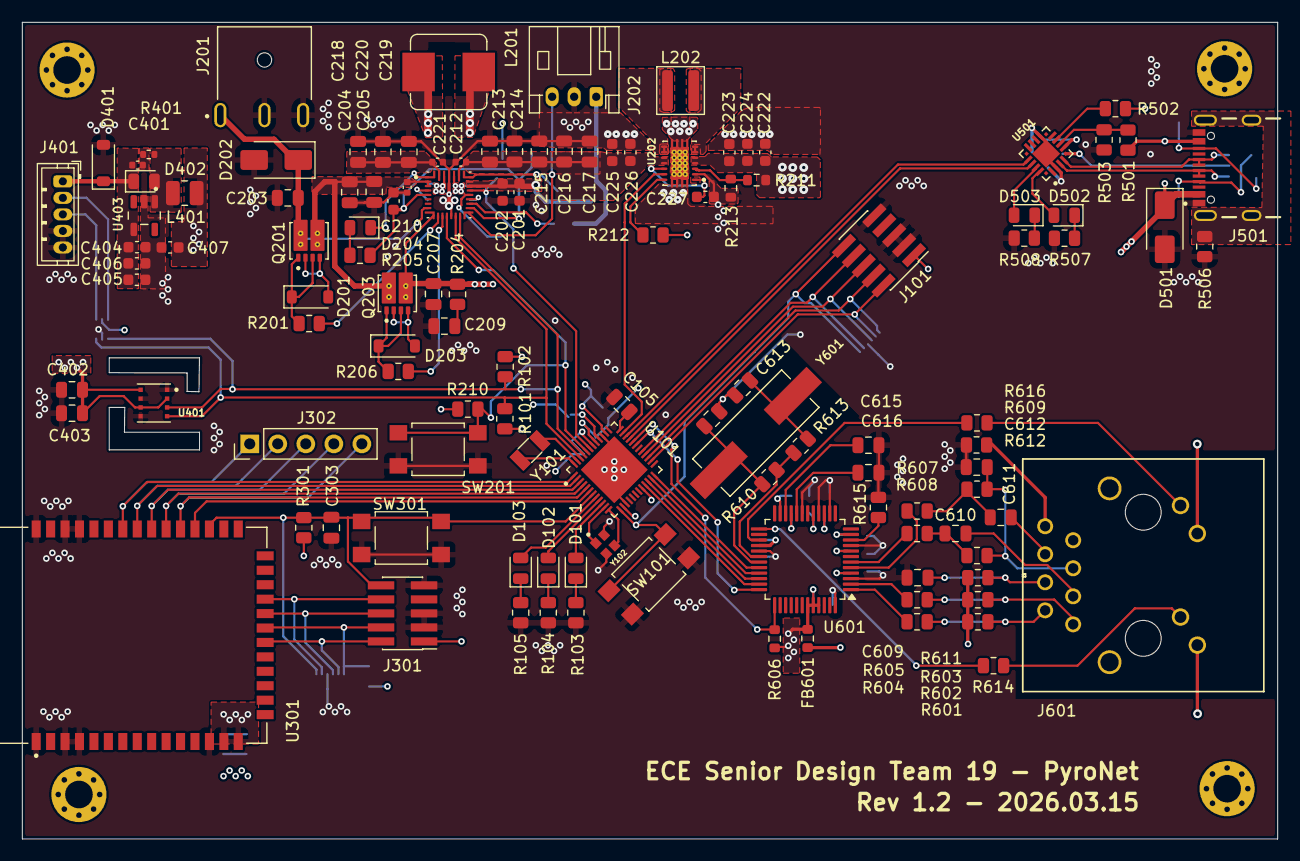
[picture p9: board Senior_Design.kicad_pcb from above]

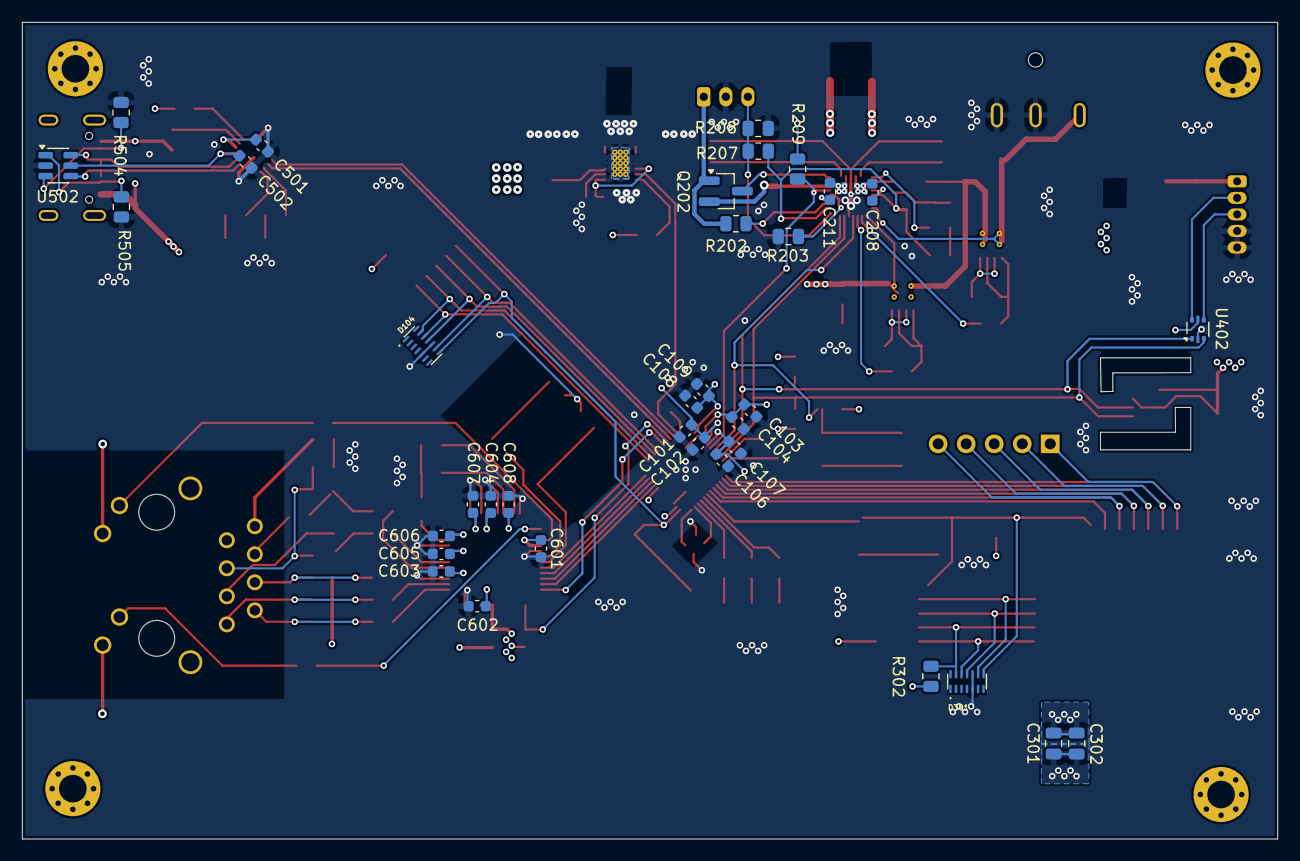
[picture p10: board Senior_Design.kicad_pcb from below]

Board: 4 copper layers, 113.8 x 74.0 mm, 154 parts (35 on the bottom side), 113 nets.

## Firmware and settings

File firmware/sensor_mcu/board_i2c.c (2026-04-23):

#include "board_i2c.h"

#include "em_cmu.h"
#include "em_gpio.h"
#include "em_i2c.h"

#define BOARD_I2C_INSTANCE            I2C0
#define BOARD_I2C_CLOCK               cmuClock_I2C0
#define BOARD_I2C_ROUTE_INDEX         0U
#define BOARD_I2C_SCL_PORT            gpioPortD
#define BOARD_I2C_SCL_PIN             2U
#define BOARD_I2C_SDA_PORT            gpioPortD
#define BOARD_I2C_SDA_PIN             3U
#define BOARD_I2C_RECOVERY_CLOCKS     9U
#define BOARD_I2C_POLL_LIMIT          10000U

static void board_i2c_short_delay(void)
{
  volatile uint32_t delay = 256U;

  while (delay-- > 0U) {
  }
}

static void board_i2c_recover_bus(void)
{
  uint32_t pulse;

  GPIO_PinModeSet(BOARD_I2C_SCL_PORT,
                  BOARD_I2C_SCL_PIN,
                  gpioModeWiredAndPullUp,
                  1U);
  GPIO_PinModeSet(BOARD_I2C_SDA_PORT,
                  BOARD_I2C_SDA_PIN,
                  gpioModeWiredAndPullUp,
                  1U);

  for (pulse = 0U; pulse < BOARD_I2C_RECOVERY_CLOCKS; pulse++) {
    GPIO_PinOutClear(BOARD_I2C_SCL_PORT, BOARD_I2C_SCL_PIN);
    board_i2c_short_delay();
    GPIO_PinOutSet(BOARD_I2C_SCL_PORT, BOARD_I2C_SCL_PIN);
    board_i2c_short_delay();
  }
}

static void board_i2c_route_pins(void)
{
  GPIO->I2CROUTE[BOARD_I2C_ROUTE_INDEX].ROUTEEN = 0U;
  GPIO->I2CROUTE[BOARD_I2C_ROUTE_INDEX].SCLROUTE =
    ((uint32_t)BOARD_I2C_SCL_PIN << _GPIO_I2C_SCLROUTE_PIN_SHIFT)
    | ((uint32_t)BOARD_I2C_SCL_PORT << _GPIO_I2C_SCLROUTE_PORT_SHIFT);
  GPIO->I2CROUTE[BOARD_I2C_ROUTE_INDEX].SDAROUTE =
    ((uint32_t)BOARD_I2C_SDA_PIN << _GPIO_I2C_SDAROUTE_PIN_SHIFT)
    | ((uint32_t)BOARD_I2C_SDA_PORT << _GPIO_I2C_SDAROUTE_PORT_SHIFT);
  GPIO->I2CROUTE[BOARD_I2C_ROUTE_INDEX].ROUTEEN =
    GPIO_I2C_ROUTEEN_SCLPEN | GPIO_I2C_ROUTEEN_SDAPEN;
}

static board_i2c_transfer_status_t board_i2c_map_status(I2C_TransferReturn_TypeDef status)
{
  switch (status) {
    case i2cTransferDone:
      return BOARD_I2C_STATUS_OK;
    case i2cTransferNack:
      return BOARD_I2C_STATUS_NACK;
    case i2cTransferBusErr:
      return BOARD_I2C_STATUS_BUS_ERROR;
    case i2cTransferArbLost:
      return BOARD_I2C_STATUS_ARB_LOST;
    default:
      return BOARD_I2C_STATUS_SW_FAULT;
  }
}

static board_i2c_transfer_status_t board_i2c_run_transfer(I2C_TransferSeq_TypeDef *sequence)
{
  I2C_TransferReturn_TypeDef status;
  uint32_t polls = 0U;

  status = I2C_TransferInit(BOARD_I2C_INSTANCE, sequence);
  while ((status == i2cTransferInProgress) && (polls < BOARD_I2C_POLL_LIMIT)) {
    status = I2C_Transfer(BOARD_I2C_INSTANCE);
    polls++;
  }

  if (status == i2cTransferInProgress) {
    return BOARD_I2C_STATUS_TIMEOUT;
  }

  return board_i2c_map_status(status);
}

board_i2c_init_result_t board_i2c_init(void)
{
  I2C_Init_TypeDef init = I2C_INIT_DEFAULT;
  board_i2c_init_result_t result;

  CMU_ClockEnable(cmuClock_GPIO, true);
  CMU_ClockEnable(BOARD_I2C_CLOCK, true);

  result.scl_before = GPIO_PinInGet(BOARD_I2C_SCL_PORT, BOARD_I2C_SCL_PIN);
  result.sda_before = GPIO_PinInGet(BOARD_I2C_SDA_PORT, BOARD_I2C_SDA_PIN);

  board_i2c_recover_bus();

  result.scl_after_recovery = GPIO_PinInGet(BOARD_I2C_SCL_PORT, BOARD_I2C_SCL_PIN);
  result.sda_after_recovery = GPIO_PinInGet(BOARD_I2C_SDA_PORT, BOARD_I2C_SDA_PIN);

  board_i2c_route_pins();

  I2C_Reset(BOARD_I2C_INSTANCE);
  init.freq = I2C_FREQ_STANDARD_MAX;
  I2C_Init(BOARD_I2C_INSTANCE, &init);

  result.frequency_hz = I2C_BusFreqGet(BOARD_I2C_INSTANCE);
  return result;
}

board_i2c_transfer_status_t board_i2c_probe(uint8_t address)
{
  I2C_TransferSeq_TypeDef seq = { 0 };
  uint8_t dummy = 0U;

  seq.addr = (uint16_t)(address << 1);
  seq.flags = I2C_FLAG_WRITE;
  seq.buf[0].data = &dummy;
  seq.buf[0].len = 0U;

  return board_i2c_run_transfer(&seq);
}

board_i2c_transfer_status_t board_i2c_write(uint8_t address,
                                            const uint8_t *data,
                                            uint16_t length)
{
  I2C_TransferSeq_TypeDef seq = { 0 };

  seq.addr = (uint16_t)(address << 1);
  seq.flags = I2C_FLAG_WRITE;
  seq.buf[0].data = (uint8_t *)data;
  seq.buf[0].len = length;

  return board_i2c_run_transfer(&seq);
}

board_i2c_transfer_status_t board_i2c_read(uint8_t address,
                                           uint8_t *data,
                                           uint16_t length)
{
  I2C_TransferSeq_TypeDef seq = { 0 };

  seq.addr = (uint16_t)(address << 1);
  seq.flags = I2C_FLAG_READ;
  seq.buf[0].data = data;
  seq.buf[0].len = length;

  return board_i2c_run_transfer(&seq);
}
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

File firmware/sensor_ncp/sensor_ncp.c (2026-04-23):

/*
 * Copyright (c) 2015-2019, Texas Instruments Incorporated
 * All rights reserved.
 *
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
 * *  Redistributions of source code must retain the above copyright
 *    notice, this list of conditions and the following disclaimer.
 *
 * *  Redistributions in binary form must reproduce the above copyright
 *    notice, this list of conditions and the following disclaimer in the
 *    documentation and/or other materials provided with the distribution.
 *
 * *  Neither the name of Texas Instruments Incorporated nor the names of
 *    its contributors may be used to endorse or promote products derived
 *    from this software without specific prior written permission.
 *
 * THIS SOFTWARE IS PROVIDED BY THE COPYRIGHT HOLDERS AND CONTRIBUTORS "AS IS"
 * AND ANY EXPRESS OR IMPLIED WARRANTIES, INCLUDING, BUT NOT LIMITED TO,
 * THE IMPLIED WARRANTIES OF MERCHANTABILITY AND FITNESS FOR A PARTICULAR
 * PURPOSE ARE DISCLAIMED. IN NO EVENT SHALL THE COPYRIGHT OWNER OR
 * CONTRIBUTORS BE LIABLE FOR ANY DIRECT, INDIRECT, INCIDENTAL, SPECIAL,
 * EXEMPLARY, OR CONSEQUENTIAL DAMAGES (INCLUDING, BUT NOT LIMITED TO,
 * PROCUREMENT OF SUBSTITUTE GOODS OR SERVICES; LOSS OF USE, DATA, OR PROFITS;
 * OR BUSINESS INTERRUPTION) HOWEVER CAUSED AND ON ANY THEORY OF LIABILITY,
 * WHETHER IN CONTRACT, STRICT LIABILITY, OR TORT (INCLUDING NEGLIGENCE OR
 * OTHERWISE) ARISING IN ANY WAY OUT OF THE USE OF THIS SOFTWARE,
 * EVEN IF ADVISED OF THE POSSIBILITY OF SUCH DAMAGE.
 */

/*
 *  ======== sensor_ncp.c ========
 */

#include <stddef.h>

/* Driver Header files */
#include <ti/drivers/GPIO.h>
// #include <ti/drivers/I2C.h>
// #include <ti/drivers/SPI.h>
// #include <ti/drivers/Watchdog.h>

#include "swo_debug.h"
#include "uart_transport.h"

/*
 *  ======== mainThread ========
 */
void *mainThread(void *arg0)
{
    (void)arg0;

    /* Call driver init functions */
    GPIO_init();
    swoDebugInitOrDie();
    swoDebugBootSelfTest("BOOT", "host_link=starting");
    // I2C_init();
    // SPI_init();
    // Watchdog_init();

    uartTransportRun();

    return NULL;
}

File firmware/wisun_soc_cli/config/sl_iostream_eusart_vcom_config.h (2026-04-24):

/***************************************************************************//**
 * @file
 * @brief IOSTREAM_EUSART Config.
 *******************************************************************************
 * # License
 * <b>Copyright 2020 Silicon Laboratories Inc. www.silabs.com</b>
 *******************************************************************************
 *
 * SPDX-License-Identifier: Zlib
 *
 * The licensor of this software is Silicon Laboratories Inc.
 *
 * This software is provided 'as-is', without any express or implied
 * warranty. In no event will the authors be held liable for any damages
 * arising from the use of this software.
 *
 * Permission is granted to anyone to use this software for any purpose,
 * including commercial applications, and to alter it and redistribute it
 * freely, subject to the following restrictions:
 *
 * 1. The origin of this software must not be misrepresented; you must not
 *    claim that you wrote the original software. If you use this software
 *    in a product, an acknowledgment in the product documentation would be
 *    appreciated but is not required.
 * 2. Altered source versions must be plainly marked as such, and must not be
 *    misrepresented as being the original software.
 * 3. This notice may not be removed or altered from any source distribution.
 *
 ******************************************************************************/

#ifndef SL_IOSTREAM_EUSART_VCOM_CONFIG_H
#define SL_IOSTREAM_EUSART_VCOM_CONFIG_H

// <<< Use Configuration Wizard in Context Menu >>>

// <h>EUART settings

// <q SL_IOSTREAM_EUSART_VCOM_ENABLE_HIGH_FREQUENCY> Enable High frequency mode
// <i> Default: 1
#define SL_IOSTREAM_EUSART_VCOM_ENABLE_HIGH_FREQUENCY        1

// <o SL_IOSTREAM_EUSART_VCOM_BAUDRATE> Baud rate
// <i> Default: 115200
#define SL_IOSTREAM_EUSART_VCOM_BAUDRATE              115200

// <o SL_IOSTREAM_EUSART_VCOM_PARITY> Parity mode to use
// <SL_IOSTREAM_EUSART_UART_NO_PARITY=> No Parity
// <SL_IOSTREAM_EUSART_UART_EVEN_PARITY=> Even parity
// <SL_IOSTREAM_EUSART_UART_ODD_PARITY=> Odd parity
// <i> Default: SL_IOSTREAM_EUSART_UART_NO_PARITY
#define SL_IOSTREAM_EUSART_VCOM_PARITY                SL_IOSTREAM_EUSART_UART_NO_PARITY

// <o SL_IOSTREAM_EUSART_VCOM_STOP_BITS> Number of stop bits to use.
// <SL_IOSTREAM_EUSART_UART_STOP_BITS_0P5=> 0.5 stop bits
// <SL_IOSTREAM_EUSART_UART_STOP_BITS_1=> 1 stop bits
// <SL_IOSTREAM_EUSART_UART_STOP_BITS_1P5=> 1.5 stop bits
// <SL_IOSTREAM_EUSART_UART_STOP_BITS_2=> 2 stop bits
// <i> Default: SL_IOSTREAM_EUSART_UART_STOP_BITS_1
#define SL_IOSTREAM_EUSART_VCOM_STOP_BITS             SL_IOSTREAM_EUSART_UART_STOP_BITS_1

// <o SL_IOSTREAM_EUSART_VCOM_FLOW_CONTROL_TYPE> Flow control
// <SL_IOSTREAM_EUSART_UART_FLOW_CTRL_NONE=> None
// <SL_IOSTREAM_EUSART_UART_FLOW_CTRL_CTS=> CTS
// <SL_IOSTREAM_EUSART_UART_FLOW_CTRL_RTS=> RTS
// <SL_IOSTREAM_EUSART_UART_FLOW_CTRL_CTS_RTS=> CTS/RTS
// <SL_IOSTREAM_EUSART_UART_FLOW_CTRL_SOFT=> Software Flow control (XON/XOFF)
// <i> Default: SL_IOSTREAM_EUSART_UART_FLOW_CTRL_NONE
#define SL_IOSTREAM_EUSART_VCOM_FLOW_CONTROL_TYPE     SL_IOSTREAM_EUSART_UART_FLOW_CTRL_NONE

// <o SL_IOSTREAM_EUSART_VCOM_RX_BUFFER_SIZE> Receive buffer size
// <i> Default: 32
#define SL_IOSTREAM_EUSART_VCOM_RX_BUFFER_SIZE    128

// <q SL_IOSTREAM_EUSART_VCOM_CONVERT_BY_DEFAULT_LF_TO_CRLF> Convert \n to \r\n
// <i> It can be changed at runtime using the C API.
// <i> Default: 0
#define SL_IOSTREAM_EUSART_VCOM_CONVERT_BY_DEFAULT_LF_TO_CRLF     true

// <q SL_IOSTREAM_EUSART_VCOM_RESTRICT_ENERGY_MODE_TO_ALLOW_RECEPTION> Restrict the energy mode to allow the reception.
// <i> Default: 1
// <i> Limits the lowest energy mode the system can sleep to in order to keep the reception on. May cause higher power consumption.
#define SL_IOSTREAM_EUSART_VCOM_RESTRICT_ENERGY_MODE_TO_ALLOW_RECEPTION    1

// </h>

// <<< end of configuration section >>>

// <<< sl:start pin_tool >>>
// <eusart signal=TX,RX,(CTS),(RTS)> SL_IOSTREAM_EUSART_VCOM
// $[EUSART_SL_IOSTREAM_EUSART_VCOM]
#define SL_IOSTREAM_EUSART_VCOM_PERIPHERAL       EUSART0
#define SL_IOSTREAM_EUSART_VCOM_PERIPHERAL_NO    0

// EUSART0 TX on PA08
#define SL_IOSTREAM_EUSART_VCOM_TX_PORT          SL_GPIO_PORT_A
#define SL_IOSTREAM_EUSART_VCOM_TX_PIN           8

// EUSART0 RX on PA09
#define SL_IOSTREAM_EUSART_VCOM_RX_PORT          SL_GPIO_PORT_A
#define SL_IOSTREAM_EUSART_VCOM_RX_PIN           9

// EUSART0 CTS on PA10
#define SL_IOSTREAM_EUSART_VCOM_CTS_PORT         SL_GPIO_PORT_A
#define SL_IOSTREAM_EUSART_VCOM_CTS_PIN          10

// EUSART0 RTS on PA00
#define SL_IOSTREAM_EUSART_VCOM_RTS_PORT         SL_GPIO_PORT_A
#define SL_IOSTREAM_EUSART_VCOM_RTS_PIN          0

// [EUSART_SL_IOSTREAM_EUSART_VCOM]$
// <<< sl:end pin_tool >>>

#endif

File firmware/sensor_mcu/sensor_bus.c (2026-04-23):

#include "sensor_bus.h"

#include <stdio.h>

static const char *sensor_bus_status_name(board_i2c_transfer_status_t status)
{
  switch (status) {
    case BOARD_I2C_STATUS_OK:
      return "ok";
    case BOARD_I2C_STATUS_NACK:
      return "nack";
    case BOARD_I2C_STATUS_BUS_ERROR:
      return "bus-error";
    case BOARD_I2C_STATUS_ARB_LOST:
      return "arb-lost";
    case BOARD_I2C_STATUS_TIMEOUT:
      return "timeout";
    case BOARD_I2C_STATUS_SW_FAULT:
    default:
      return "sw-fault";
  }
}

static void sensor_bus_log_probe_result(const char *name,
                                        uint8_t address,
                                        board_i2c_transfer_status_t status)
{
  if (status == BOARD_I2C_STATUS_OK) {
    printf("SENSOR_FOUND name=%s addr=0x%02X\r\n", name, address);
    return;
  }

  printf("SENSOR_PROBE name=%s addr=0x%02X status=%s\r\n",
         name,
         address,
         sensor_bus_status_name(status));
}

sensor_bus_state_t sensor_bus_init(void)
{
  sensor_bus_state_t state = { 0 };

  state.i2c = board_i2c_init();

  printf("I2C_LINES before scl=%u sda=%u\r\n",
         state.i2c.scl_before,
         state.i2c.sda_before);
  printf("I2C_LINES after-recovery scl=%u sda=%u\r\n",
         state.i2c.scl_after_recovery,
         state.i2c.sda_after_recovery);
  printf("I2C_READY bus=I2C0 freq=%lu scl=PD02 sda=PD03\r\n",
         (unsigned long)state.i2c.frequency_hz);

  state.sps30_status = board_i2c_probe(SENSOR_BUS_SPS30_ADDRESS);
  state.sps30_present = (state.sps30_status == BOARD_I2C_STATUS_OK);
  sensor_bus_log_probe_result("SPS30", SENSOR_BUS_SPS30_ADDRESS, state.sps30_status);

  if ((state.sps30_status != BOARD_I2C_STATUS_OK)
      && (state.sps30_status != BOARD_I2C_STATUS_NACK)) {
    state.i2c = board_i2c_init();
  }

  state.bme68x_status = board_i2c_probe(SENSOR_BUS_BME68X_ADDRESS);
  state.bme68x_present = (state.bme68x_status == BOARD_I2C_STATUS_OK);
  sensor_bus_log_probe_result("BME68x", SENSOR_BUS_BME68X_ADDRESS, state.bme68x_status);

  return state;
}

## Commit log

2026-02-22 Initial git commit
    [BDE-MB1352P71UA32.kicad_sch, BME688_SPS3-.kicad_sch, MCU_Connections.kicad_pcb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]
2026-02-27 simple changes to the Pulse leds
    [USBC.kicad_sch]
2026-03-01 Debugging LED added
    [BDE-MB1352P71UA32.kicad_sch, BME688_SPS3-.kicad_sch, USBC.kicad_sch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]
2026-03-03 Intergrated 3.3V BuckBoost and 5V Boost
2026-03-03 Added thermistor connection
    [psu.kicad_sch]
2026-03-03 Added LF crystal
    [mcu.kicad_sch]
2026-03-03 Unified I2C pull-ups to MCU page
    [BME688_SPS3-.kicad_sch, Senior_Design.kicad_sch, mcu.kicad_sch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]
2026-03-03 RFVDD/PAVDD wip
    [mcu.kicad_sch]
2026-03-03 removed Ethernet LED diodes
    [ethernet.kicad_sch]
2026-03-03 MCU Reset Pin fix
    [mcu.kicad_sch, psu.kicad_sch]
2026-03-03 MCU Capacitor Updates
    [mcu.kicad_sch]
2026-03-04 Fixed MCU JTAG/Reordered pages
    [BDE-MB1352P71UA32.kicad_sch, BME688_SPS3-.kicad_sch, Senior_Design.kicad_sch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]
2026-03-04 Fixed MCU power pins
    [mcu.kicad_sch]
2026-03-04 BDE JTAG pullup
    [BDE-MB1352P71UA32.kicad_sch]
2026-03-04 Replaced 3.3V symbol
    [BDE-MB1352P71UA32.kicad_sch, BME688_SPS3-.kicad_sch, Senior_Design.kicad_sch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]
2026-03-05 deleted unsused files/folders
    [MCU_Connections.kicad_pcb, MCU_Connections.kicad_sch, MCU_discretecomp.kicad_sch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]
2026-03-05 added footprint/symbols
2026-03-05 updated major symbol and footprints
    [BDE-MB1352P71UA32.kicad_sch, BME688_SPS3-.kicad_sch, Senior_Design.kicad_sch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]
2026-03-05 updated 5V power and pin
    [BDE-MB1352P71UA32.kicad_sch, BME688_SPS3-.kicad_sch, Senior_Design.kicad_sch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]
2026-03-05 passing ERC w/ exclusions
    [BME688_SPS3-.kicad_sch, USBC.kicad_sch, ethernet.kicad_sch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]
2026-03-05 updated annotations
    [BDE-MB1352P71UA32.kicad_sch, BME688_SPS3-.kicad_sch, USBC.kicad_sch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]
2026-03-06 added ship fet
    [BDE-MB1352P71UA32.kicad_sch, USBC.kicad_sch, ethernet.kicad_sch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]
2026-03-06 footprint update
    [BDE-MB1352P71UA32.kicad_sch, BME688_SPS3-.kicad_sch, Senior_Design.kicad_pcb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]
2026-03-06 footprint update 2
    [BDE-MB1352P71UA32.kicad_sch, BME688_SPS3-.kicad_sch, Senior_Design.kicad_pcb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]
2026-03-06 updated ESD/Inductor footprints
    [BME688_SPS3-.kicad_sch, USBC.kicad_sch, ethernet.kicad_sch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]
2026-03-06 Buck/Bost layouts and part of BMS
    [Senior_Design.kicad_pcb]
2026-03-06 updated footprints
    [BDE-MB1352P71UA32.kicad_sch, BME688_SPS3-.kicad_sch, Senior_Design.kicad_pcb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]
2026-03-07 updated labels
    [BDE-MB1352P71UA32.kicad_sch, BME688_SPS3-.kicad_sch, Senior_Design.kicad_pcb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]
2026-03-07 fixed ERC issues
    [ethernet.kicad_sch, mcu.kicad_sch, psu.kicad_sch]
2026-03-07 added QON pushbutton
    [Senior_Design.kicad_pcb]
2026-03-07 PCB footprint update
    [psu.kicad_sch]
2026-03-07 BDE footprint/new 5V boost
    [BDE-MB1352P71UA32.kicad_sch, Senior_Design.kicad_pcb, psu.kicad_sch]
2026-03-08 BME/BDE pin update
    [BDE-MB1352P71UA32.kicad_sch, BME688_SPS3-.kicad_sch, Senior_Design.kicad_pcb]
2026-03-09 MCU pin reassignment
    [mcu.kicad_sch]
2026-03-09 MCU pin update
    [mcu.kicad_sch]
2026-03-09 moved layout
    [Senior_Design.kicad_pcb]
2026-03-10 ethernet layout
    [Senior_Design.kicad_pcb]
2026-03-10 BMS layout
    [Senior_Design.kicad_pcb, Senior_Design.kicad_sch, ethernet.kicad_sch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]
2026-03-10 ethernet/wisun pcb update
    [Senior_Design.kicad_pcb, ethernet.kicad_sch]
2026-03-10 PCB WIP
    [Senior_Design.kicad_pcb]
2026-03-11 Power Layout WIP
    [Senior_Design.kicad_pcb, ethernet.kicad_sch, psu.kicad_sch]
2026-03-11 5VB PCB layout
    [BME688_SPS3-.kicad_sch, Senior_Design.kicad_pcb]
2026-03-11 PCB layout update
    [Senior_Design.kicad_pcb, USBC.kicad_sch]
2026-03-11 BDE JTAG layout
    [Senior_Design.kicad_pcb]
2026-03-11 ethernet cap layout
    [Senior_Design.kicad_pcb, ethernet.kicad_sch]
2026-03-12 PCB update
    [BME688_SPS3-.kicad_sch, Senior_Design.kicad_pcb, mcu.kicad_sch]
2026-03-13 added data sheet and added some of the vias the PCB design
    [BDE-MB1352P71UA32.kicad_sch, BME688_SPS3-.kicad_sch, Senior_Design.kicad_pcb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]
2026-03-13 PCB Layout - Rev 1.0
    [BME688_SPS3-.kicad_sch, Senior_Design.kicad_pcb, ethernet.kicad_sch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]
2026-03-13 Added Mounting Holes
    [Senior_Design.kicad_pcb, USBC.kicad_sch]
2026-03-13 moved mounting holes
    [Senior_Design.kicad_pcb]
2026-03-13 minor fix
    [Senior_Design.kicad_pcb]
2026-03-13 USB move
    [Senior_Design.kicad_pcb]
2026-03-13 3dmodels update
    [BME688_SPS3-.kicad_sch, Senior_Design.kicad_pcb, USBC.kicad_sch]
2026-03-13 silkscreen update
    [Senior_Design.kicad_pcb]
2026-03-13 readded mounting holes
    [Senior_Design.kicad_pcb]
2026-03-13 3.3V via fix
    [Senior_Design.kicad_pcb]
2026-03-13 3dmodel fix
    [Senior_Design.kicad_pcb]
2026-03-13 review changes/USB next
    [BME688_SPS3-.kicad_sch, Senior_Design.kicad_pcb, psu.kicad_sch]
2026-03-14 USB update
    [BME688_SPS3-.kicad_sch, Senior_Design.kicad_pcb, USBC.kicad_sch]
2026-03-14 Rev 1.2 - debuggin pins added
    [BDE-MB1352P71UA32.kicad_sch, Senior_Design.kicad_pcb]
2026-03-14 Correction: Rev 1.1
    [Senior_Design.kicad_pcb]
2026-03-15 PCB cleanup
    [BDE-MB1352P71UA32.kicad_sch, Senior_Design.kicad_pcb, USBC.kicad_sch]
2026-03-15 no blind/buried vias
    [Senior_Design.kicad_pcb]
2026-03-16 advancedpcb contstraints
    [Senior_Design.kicad_pcb]
2026-03-16 minor updates
    [BME688_SPS3-.kicad_sch, Senior_Design.kicad_pcb, USBC.kicad_sch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]
2026-03-17 minor fixes
    [Senior_Design.kicad_pcb]
2026-03-17 PCBWay submission
    [Senior_Design.kicad_pcb]
2026-04-03 label cleanup
    [BDE-MB1352P71UA32.kicad_sch, BME688_SPS3-.kicad_sch, USBC.kicad_sch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]
2026-04-17 debug LED test - working
2026-04-18 pm2.5 sensor working
2026-04-21 SWO rework / UART wip
    [sensor_ncp.c]
2026-04-21 I2C WIP
2026-04-21 UART update
2026-04-24 working spoof device
